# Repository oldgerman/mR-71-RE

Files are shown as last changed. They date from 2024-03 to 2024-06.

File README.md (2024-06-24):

## mR-71-RE

mR-71-RE 是基于 [Andrey_B](https://www.radiokot.ru/forum/memberlist.php?mode=viewprofile&u=21307) 的作品 [交流欧姆表 mR-71](https://radiokot.ru/artfiles/6673/) 修改的

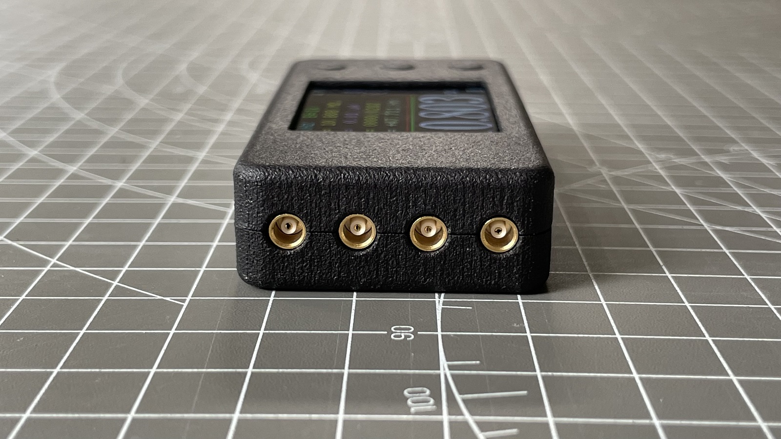
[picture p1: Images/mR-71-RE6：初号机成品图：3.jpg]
|  |
| ------------------------------------------ |

## 关于

mR-71 重制版的制造文件（mR-71 Remastered version manufacturing files）

你第一次接触到本套文件可能是压缩包，制造文件的版本可能滞后于仓库，制作前请访问[仓库地址](https://github.com/oldgerman/mR-71-RE)检查更新

The first time you come into contact with this set of files, it may be a compressed package, and the content may lag behind the warehouse. Please visit the [github](https://github.com/oldgerman/mR-71-RE) to check for updates before making

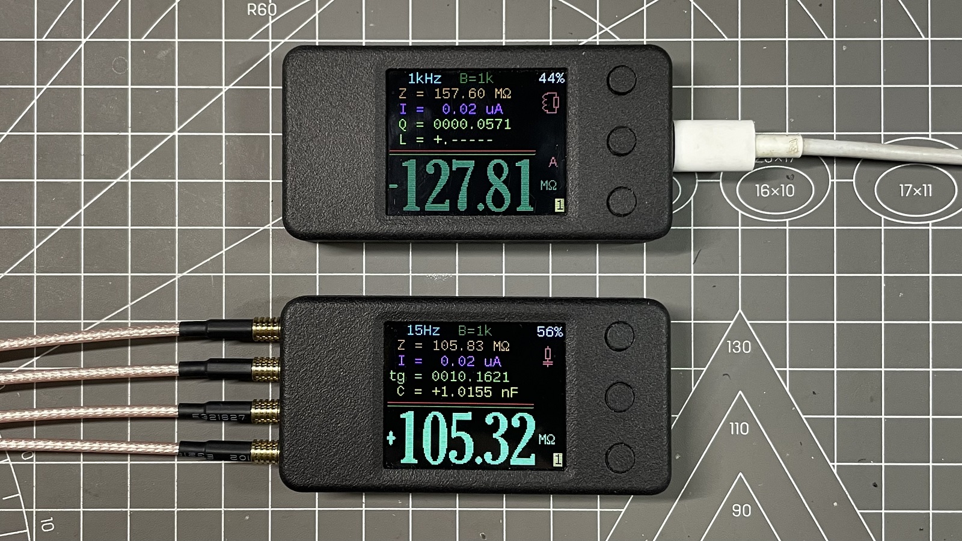
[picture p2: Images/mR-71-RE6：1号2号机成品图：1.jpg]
mR-71-RE6：1号2号机成品图：2
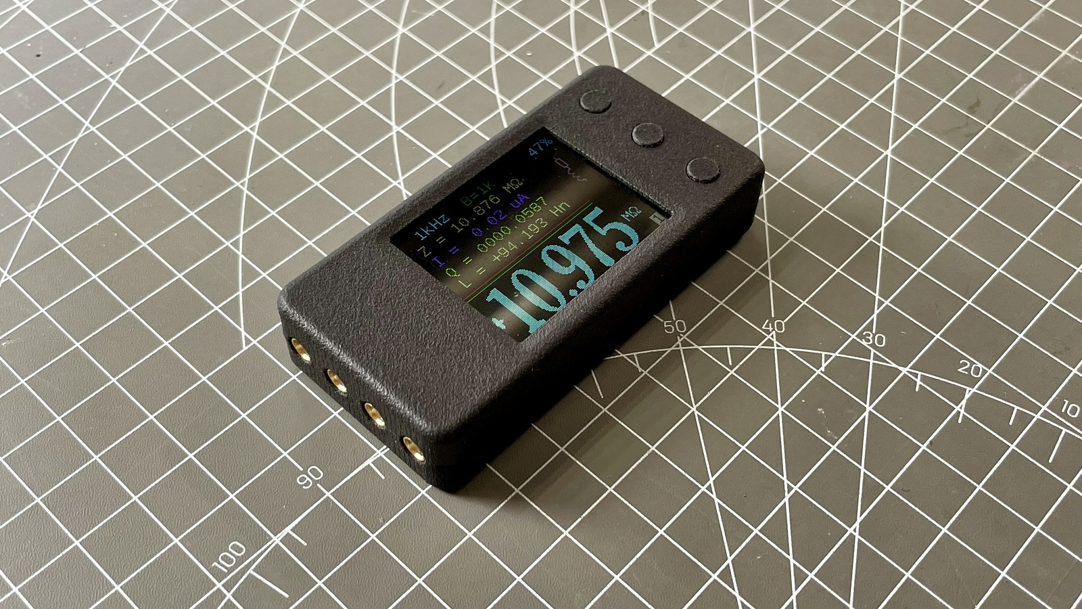
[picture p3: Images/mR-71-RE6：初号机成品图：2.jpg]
|  |  |
| --- | --- |
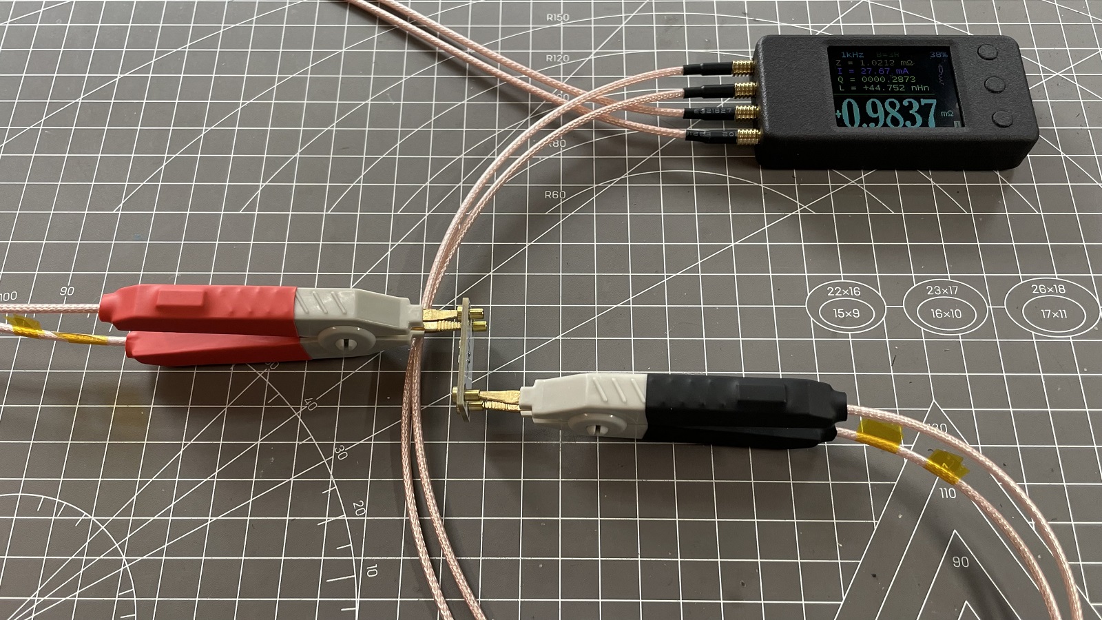
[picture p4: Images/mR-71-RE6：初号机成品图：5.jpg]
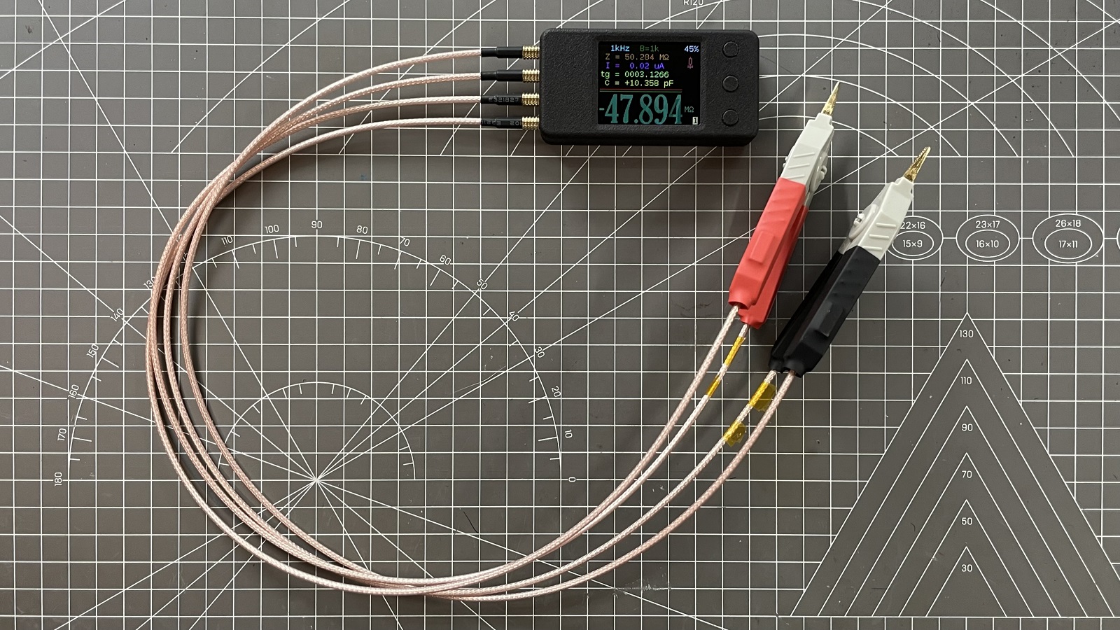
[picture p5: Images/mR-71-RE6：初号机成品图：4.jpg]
|  |  |

### 路径下各个文件夹的说明

```c
├─AD_Projects                     // # PCB的源文件
│  └─MR-71_RE0                    // # 原版mR-71重绘工程
├─BOM                             // # PCB的物料清单
├─Gerber                          // # 打板文件
│  ├─Kelvin_Clip_RG316_To_PCB     // ## 【2层，板厚1.6mm】RG316转接板
│  ├─Kelvin_RES                   // ## 【2层，板厚1.6mm】开尔文焊盘电阻测试板
│  ├─mR-71-RE                     // ## 【4层，板厚1.0mm】主板PCB打样文件
│  └─mR-71_RE_Stencil             // ## 主板开钢网的文件
├─Hex                             // # 固件: 反汇编修改v0.2固件，以适配IPS屏幕
├─Images                          // # 图片
├─Schematic                       // # 原理图
├─SMT                             // # SMT文件
└─STL                             // # 3D打印模型
    ├─link_parts                  // ## 连接模型
    └─single_parts                // ## 单个模型
```

### 快速下载某个文件

如果你想单独下载某个文件，可以顺着文件路径一路点击到对应的文件，点击下载raw文件：

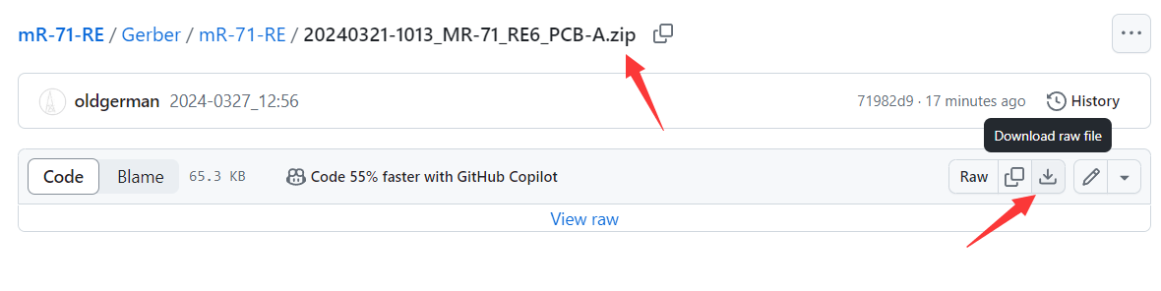
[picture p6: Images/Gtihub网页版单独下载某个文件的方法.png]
Gtihub网页版单独下载某个文件的方法


### 注意事项

- 主板 PCB 打板厚度是 1mm，否则外壳会装配不好
- PCB、原理图、钢网、外壳文件后续可能会改动，以最新的日期时间为准！

### 了解更多

- [mR-71-RE组装指南](https://oldgerman.github.io/1d2ecca7/)（网页版，可以使用浏览器翻译），本仓库根目录有 PDF 版
- [mR-71-RE校准测试](https://oldgerman.github.io/b8304ba5/)（网页版，可以使用浏览器翻译），本仓库根目录有 PDF 版

### 更新日志

| 日期 | 概述 | 制造文件变动 | 备注 |
| --- | --- | --- | --- |
| 2024-0319 | 首次发布 | 主机 PCB 版本：v1.0 | 组装教程、3D 打印外壳也都上传了 |
| 2024-0321 | 更新主机 PCB 版本、钢网、原理图 | 主机PCB版本：v1.1 | 还添加了小于 20% 沉金面积版本，后缀 Gold |
| 2024-0325 | 更新成品图 | 无 | 无 |
| 2024-0327 | 添加 mR-71-RE 上板和下板单独的 Gerber 文件 | 无 | 详见 [Gerber文件说明：mR-71-RE](https://github.com/oldgerman/mR-71-RE/blob/master/Gerber/mR-71-RE/README.md) |
| 2024-0408 | 添加 组装指南 和 校准测试 网页版文章的 PDF 版 | 原理图、BOM、ibom | 网页版文章的 PDF 版在仓库根目录下 |
| 2024-0416 | 添加 Kelvin_RES 焊盘 2512 和 1206 单独的 Gerber 文件 | 无 | 详见 [Gerber文件说明：Kelvin_RES](https://github.com/oldgerman/mR-71-RE/blob/master/Gerber/Kelvin_RES/README.md) |
| 2024-0418 | 修正 BOM 表 R31 R32 封装，从 0402 改为 0603 | 原理图、BOM | 物料种类未变 |
| 2024-0420 | 修正 BOM 表 C22 厂家型号为 CL05B103KB5NNNC | BOM | 物料种类变化 |
| 2024-0430 | 重命名交互式 BOM 文件 20240408_MR-71_RE6_BOM.html 为 20240420_MR-71_RE6_BOM.html | ibom | 仅重命名，防止不必要的误解（以为 BOM 更新了但 ibom 还是旧版本对不上号） |
| 2024-0511 | 添加 mR-71-RE 的 SMT 坐标文件 | 坐标文件 | 不同 PCB 需使用对应的坐标文件，在 [SMT](https://github.com/oldgerman/mR-71-RE/blob/master/SMT) 文件夹 |
| 2024-0512 | 添加 AD 重绘的原版 mR-71 工程 | 无 | 详见 [源文件说明：mR-71-RE0](https://github.com/oldgerman/mR-71-RE/blob/master/AD_Projects/MR-71_RE0/README.md) |
| 2024-0624 | 添加 Kelvin_RES 焊盘 2512 和 1206 单元的 Gerber 文件 | 无 | 详见 [Gerber文件说明：Kelvin_RES](https://github.com/oldgerman/mR-71-RE/blob/master/Gerber/Kelvin_RES/README.md) |

## 致谢

- 感谢 [mR-71](https://radiokot.ru/artfiles/6673/) 原作者 [Andrey_B](https://www.radiokot.ru/forum/memberlist.php?mode=viewprofile&u=21307)
- 感谢一同玩 mR-71 的老友们
- 感谢 JLC 和 JP 的板子

## 许可协议

[CC BY-NC-SA 4.0 DEED | 署名-非商业性使用-相同方式共享 4.0 国际](https://creativecommons.org/licenses/by-nc-sa/4.0/deed.zh-hans)



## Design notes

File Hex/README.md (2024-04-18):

## hex文件说明

### 20240418_mR-71_v0.2_FW_std_ida_func(ips_ok+sub_8003e90_to_foo2).hex

BUG修复：

- hex文件最后缺少回车换行，某些下载器会无法正常加载，已添加，感谢 硬汉哥 [指出BUG](https://www.armbbs.cn/forum.php?mod=redirect&goto=findpost&ptid=123517&pid=304299&fromuid=47676)

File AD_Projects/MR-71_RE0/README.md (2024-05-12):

## 源文件说明：mR-71-RE0

原版 mR-71 的 PCB 和 SCH 作者 Andery_B 使用 Sprint-Layout 绘制，没有分享源文件，因此使用其他主流 EDA 演绎非常不方便

此文件夹下是我用 Altium 23.3.1 重绘的 原版 mR-71 工程，原理图遵循原版的风格，PCB按照原版的走线方式布通，但线宽过孔按键开孔等未优化，**仅供参考，不保证做出来可以正常工作**，如果你想设计 原版 mR-71 的衍生版本，不如从这套源文件开始

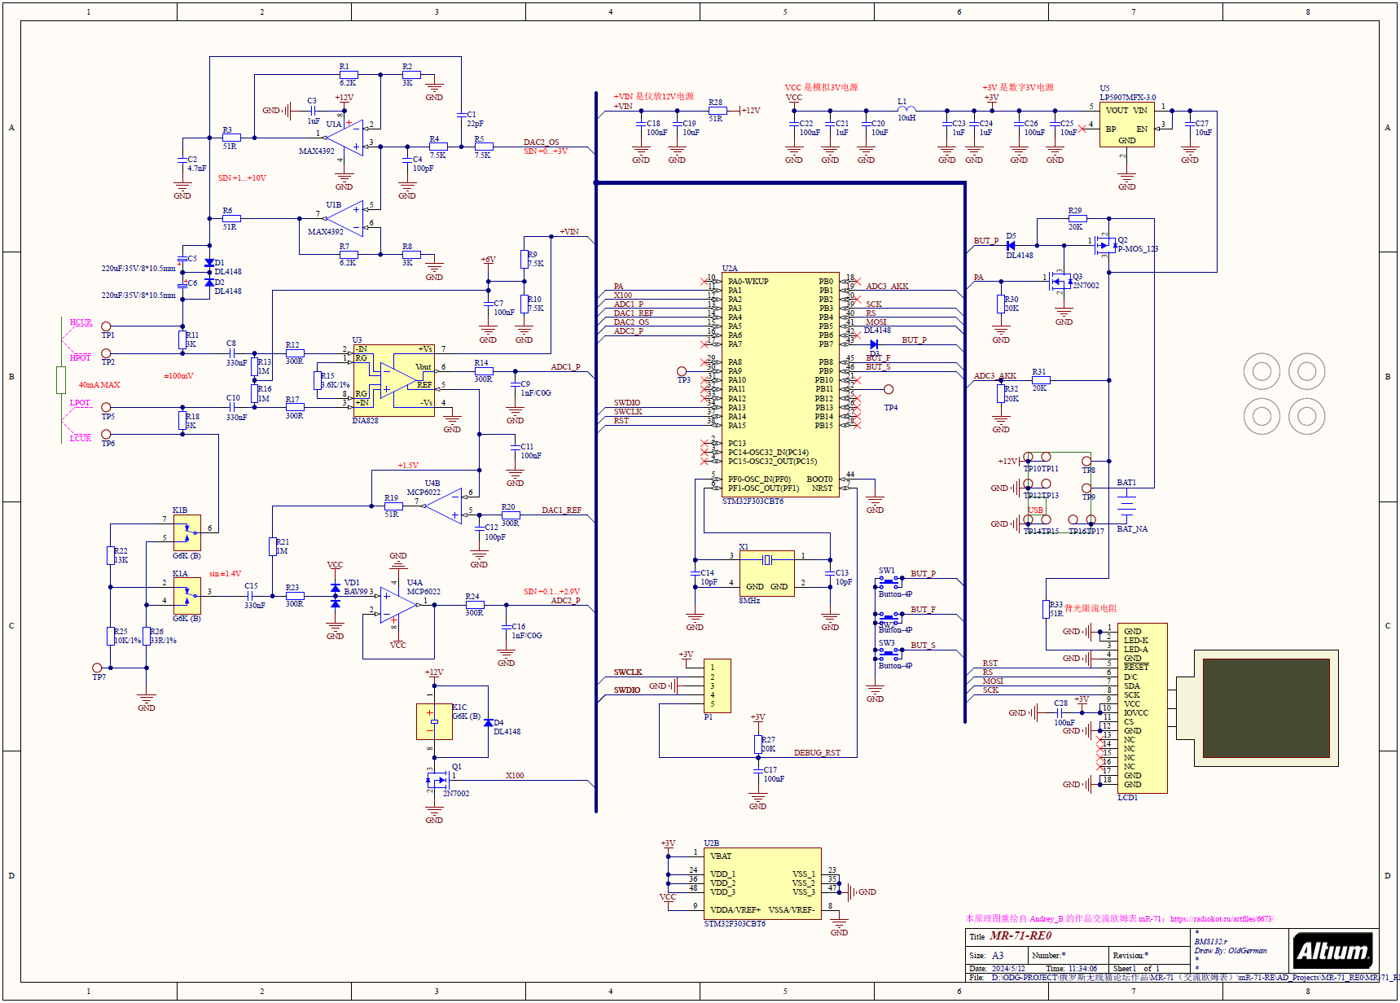
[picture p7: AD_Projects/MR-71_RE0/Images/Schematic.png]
SCH


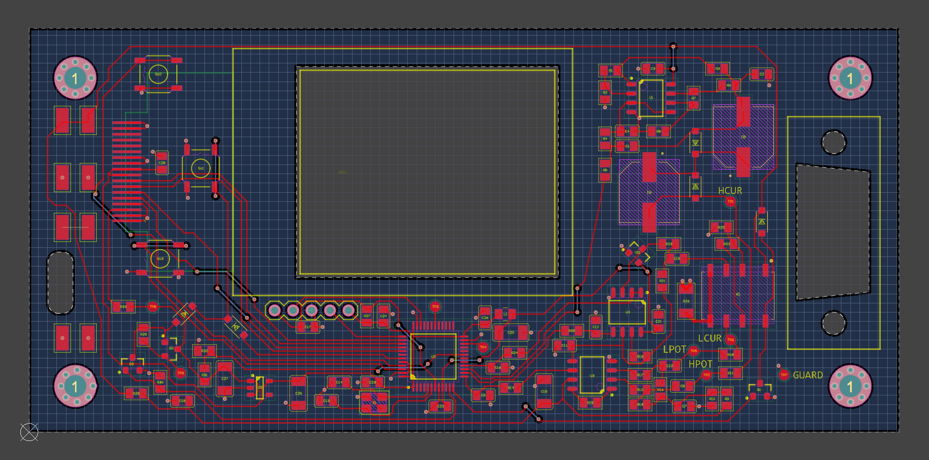
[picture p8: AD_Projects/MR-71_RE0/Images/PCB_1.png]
PCB_1


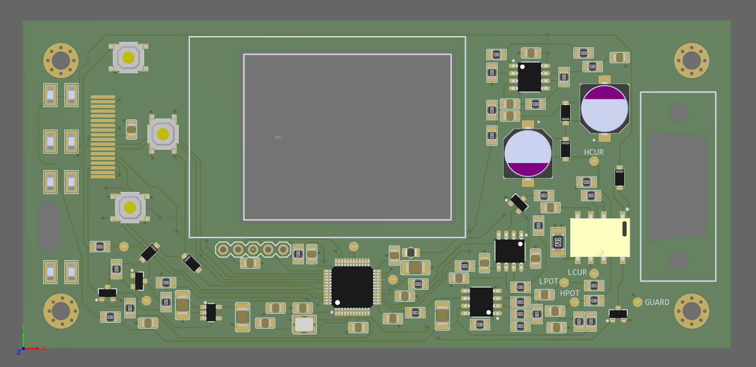
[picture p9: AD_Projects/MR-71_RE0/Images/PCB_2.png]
PCB_2


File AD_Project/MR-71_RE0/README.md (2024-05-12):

## 源文件说明：mR-71-RE0

原版 mR-71 的 PCB 和 SCH 作者 Andery_B 使用 Sprint-Layout 绘制，没有分享源文件，因此使用其他主流 EDA 演绎非常不方便

此文件夹下是我用 Altium 23.3.1 重绘的 原版 mR-71 工程，原理图遵循原版的风格，PCB按照原版的走线方式布通，但线宽过孔等未优化，**仅供参考，不保证做出来可以正常工作**，如果你想设计 原版 mR-71 的衍生版本，不如从这套源文件开始

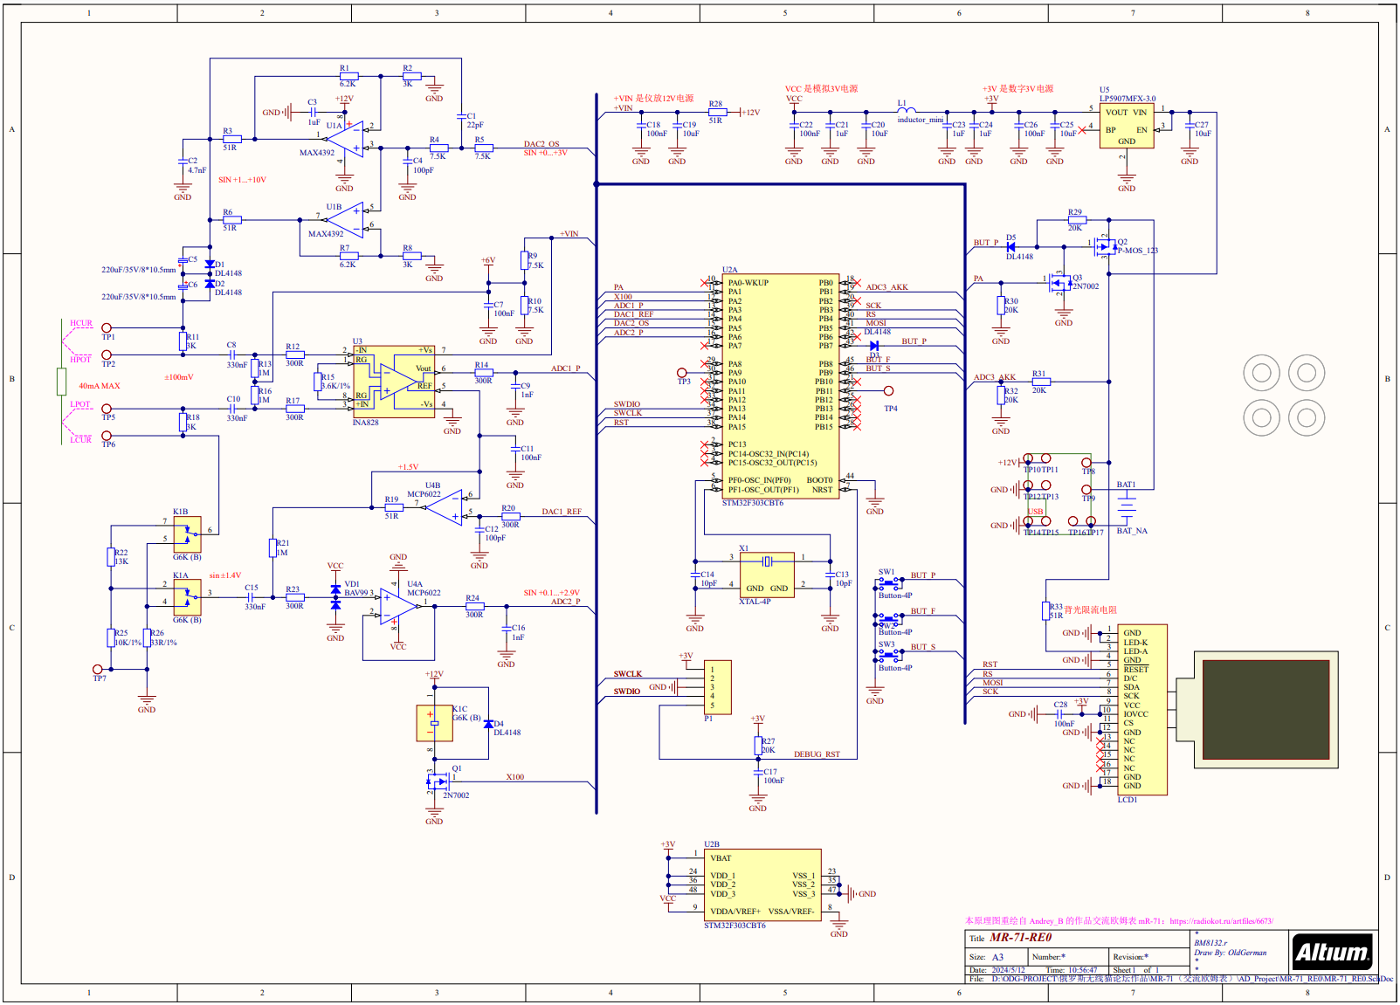
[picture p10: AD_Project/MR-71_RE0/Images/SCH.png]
SCH


PCB_1

PCB_2

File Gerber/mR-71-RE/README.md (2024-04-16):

## Gerber文件说明：mR-71-RE

### 文件名：组成

```c
AAAABBCC-DDEE_MR-71_RE6_####.zip
^~~~^~^~ ^~^~ ^~~~~~~~^ ^~~~ ^~~
年  月 日 时 分 名称  版本 后缀  格式
^~~~~~~~~~~~~
前缀
```

例如：20240321-1013_MR-71_RE6_Gold.zip 文件名的意思是：2024年3月31日MR-71-RE第6版沉金

### 文件名：前缀：日期

优先使用最新日期的文件，同一天日期后的小时分钟不分先后

### 文件名：后缀

- 无：上板和下板拼成一个板的文件，得看审核运气，若被当作拼版，就单独打后缀为 PCB-A 和 PCB-B 的文件
- Gold：小于20%沉金面积的，可用JLC沉金通用券，但得看审核运气，可能被当作拼版，不能用券
- PCB-A：上板（有显示屏、按钮的板子）
- PCB-B：下板（有主控、电源、运放的板子）

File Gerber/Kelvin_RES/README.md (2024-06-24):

## Gerber文件说明：Kelvin_RES

### 文件名：组成

```c
AAAABBCC-DDEE_Kelvin_RES_v1.0.zip
^~~~^~^~ ^~^~ ^~~~~~~~~~ ^~~~ ^~~
年  月 日 时 分 名称        版本 格式
^~~~~~~~~~~~~
前缀
```

例如：20240314-1629_Kelvin_RES_v1.0 文件名的意思是：2024年3月14日Kelvin_RES第1.0版

### 文件名：前缀：日期

优先使用最新日期的文件，同一天日期后的小时分钟不分先后

### PCB预览

#### Kelvin_RES_v1.0

同时有2512和1206焊盘

| 正面 | 反面 |
| --- | --- |
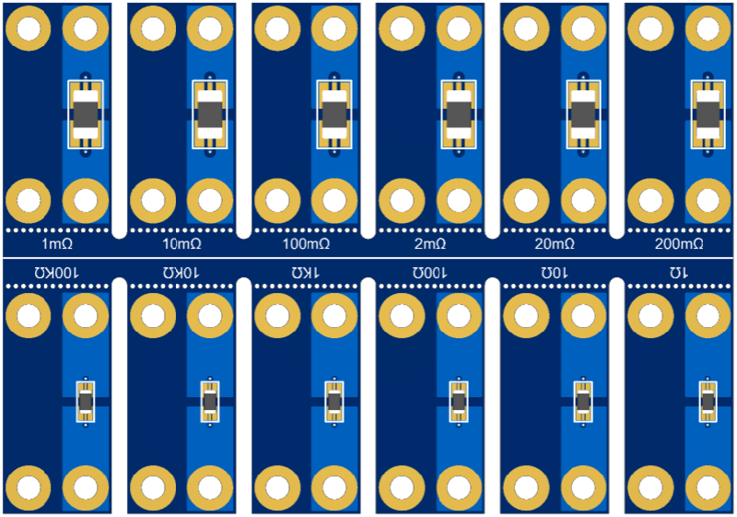
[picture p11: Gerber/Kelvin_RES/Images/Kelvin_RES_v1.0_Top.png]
Kelvin_RES_v1.0_Top
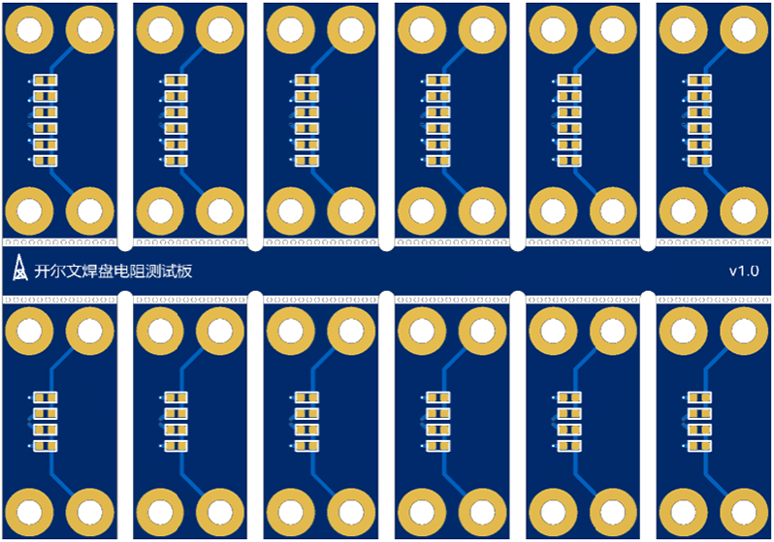
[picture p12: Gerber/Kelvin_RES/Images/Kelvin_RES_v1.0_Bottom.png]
Kelvin_RES_v1.0_Bottom
|  |  |

#### Kelvin_RES_1206_v1.0

只有1206焊盘

| 正面 | 反面 |
| --- | --- |
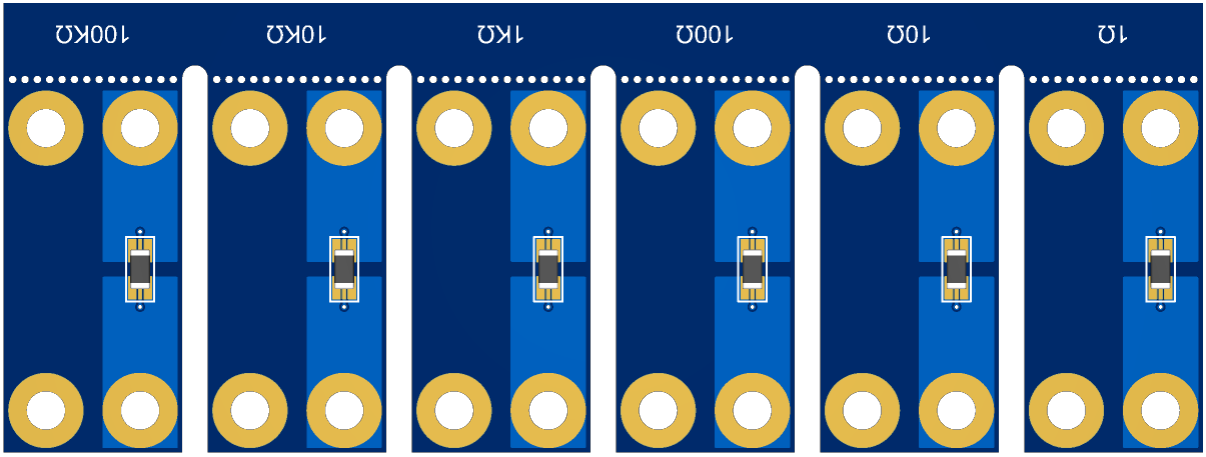
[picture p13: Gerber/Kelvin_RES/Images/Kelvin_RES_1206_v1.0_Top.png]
Kelvin_RES_1206_v1.0_Top
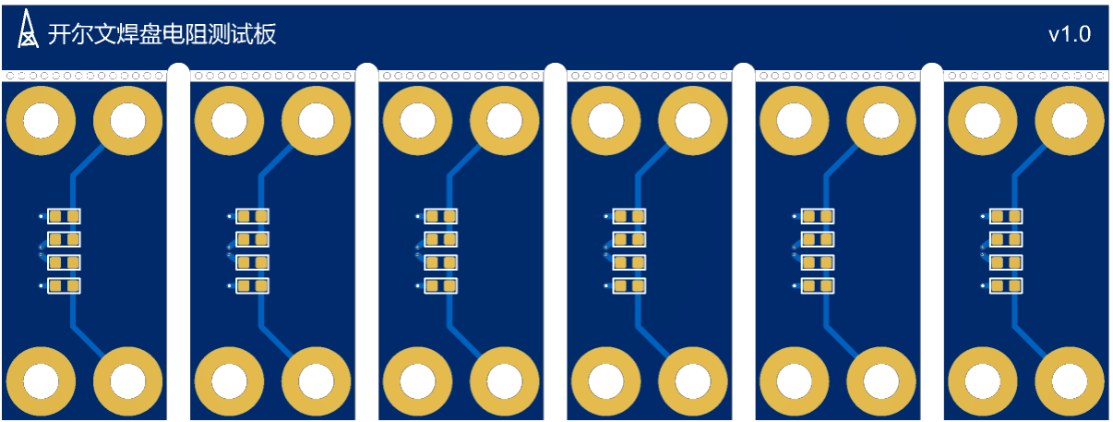
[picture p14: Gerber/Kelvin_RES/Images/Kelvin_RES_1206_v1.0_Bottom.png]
Kelvin_RES_1206_v1.0_Bottom
|  |  |

#### Kelvin_RES_2512_v1.0

只有2512焊盘

| 正面 | 反面 |
| --- | --- |
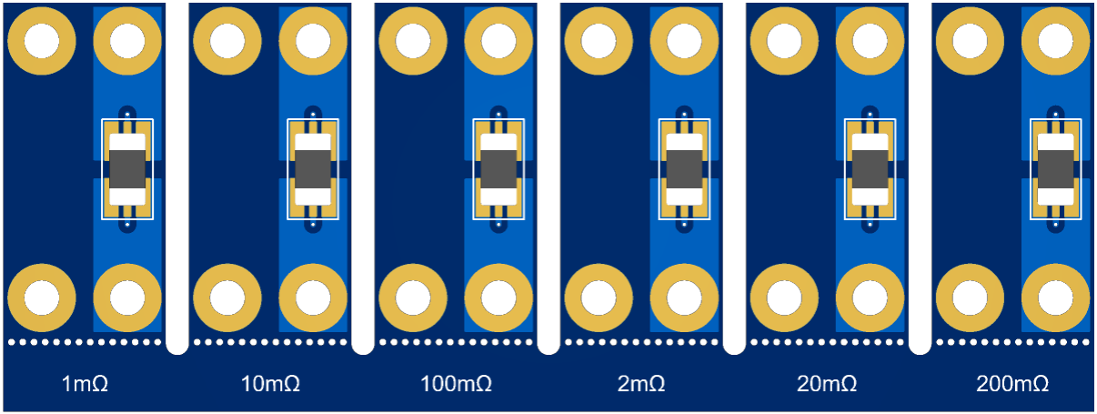
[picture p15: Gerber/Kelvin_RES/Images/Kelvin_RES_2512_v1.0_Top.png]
Kelvin_RES_2512_v1.0_Top
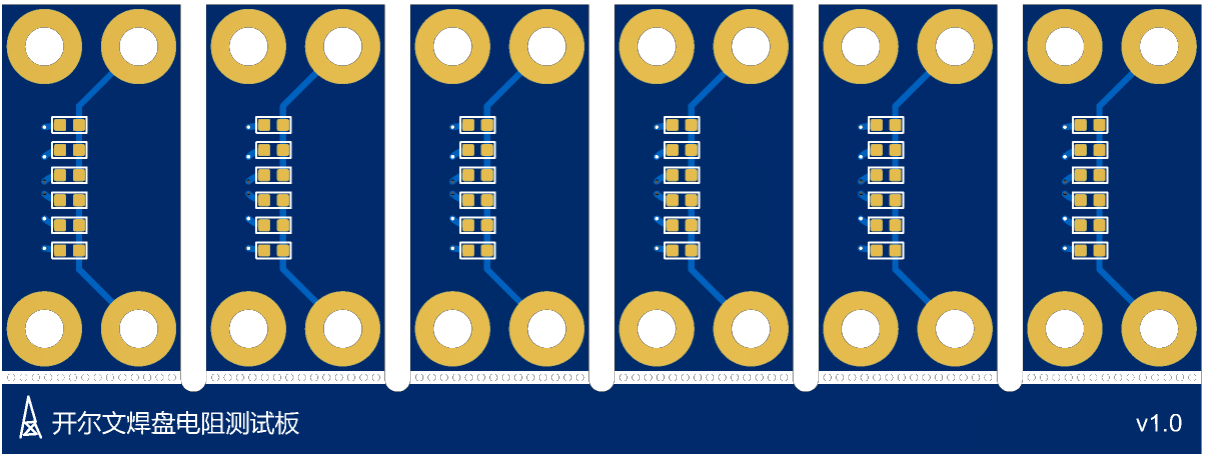
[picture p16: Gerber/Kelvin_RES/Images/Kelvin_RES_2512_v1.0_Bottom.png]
Kelvin_RES_2512_v1.0_Bottom
|  |  |

#### Kelvin_RES_Unit_1206_v1.0

| 正面 | 反面 |
| --- | --- |
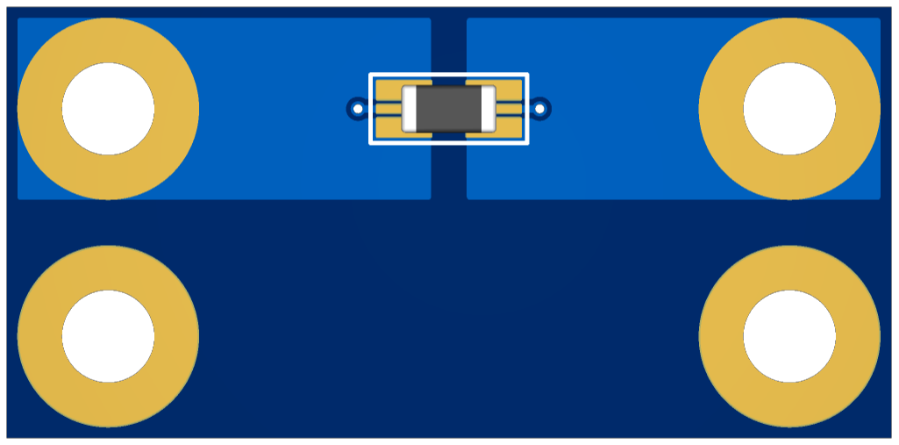
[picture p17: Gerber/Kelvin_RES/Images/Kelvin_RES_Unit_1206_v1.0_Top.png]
Kelvin_RES_Unit_1206_v1.0_Top
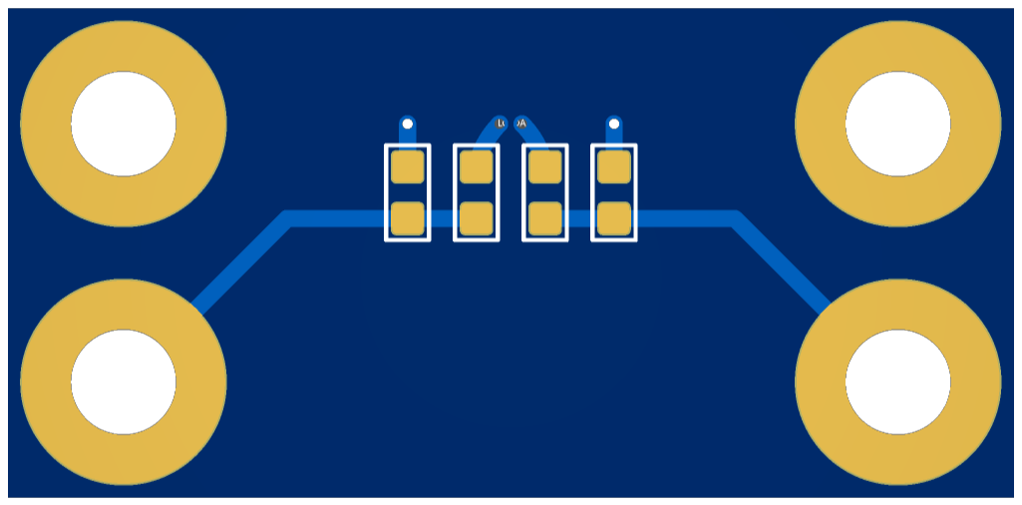
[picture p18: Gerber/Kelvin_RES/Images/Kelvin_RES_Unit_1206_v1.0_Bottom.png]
Kelvin_RES_Unit_1206_v1.0_Bottom
|  |  |

#### Kelvin_RES_Unit_2512_v1.0

| 正面 | 反面 |
| --- | --- |
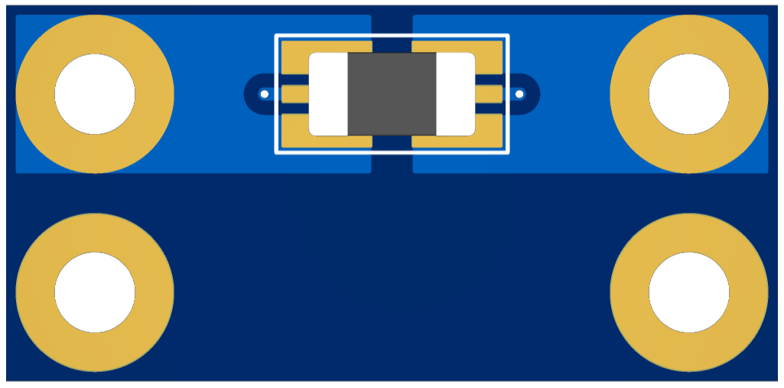
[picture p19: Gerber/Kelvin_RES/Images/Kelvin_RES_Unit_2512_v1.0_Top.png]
Kelvin_RES_Unit_2512_v1.0_Top
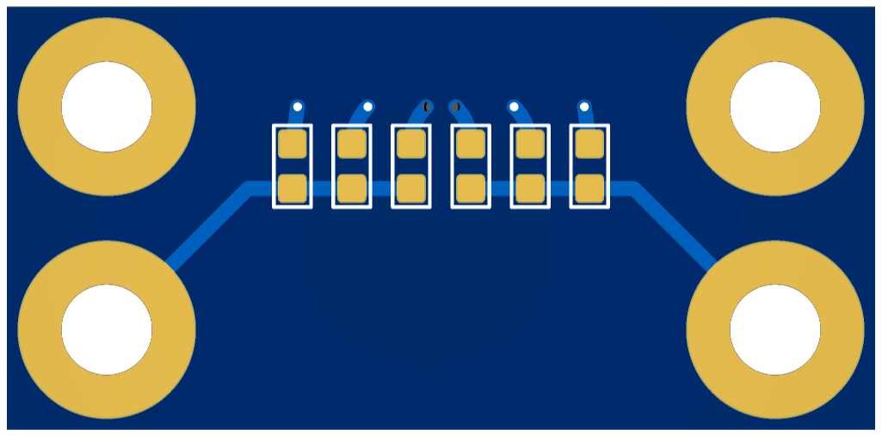
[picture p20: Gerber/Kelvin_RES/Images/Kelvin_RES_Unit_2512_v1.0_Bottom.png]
Kelvin_RES_Unit_2512_v1.0_Bottom
|  |  |

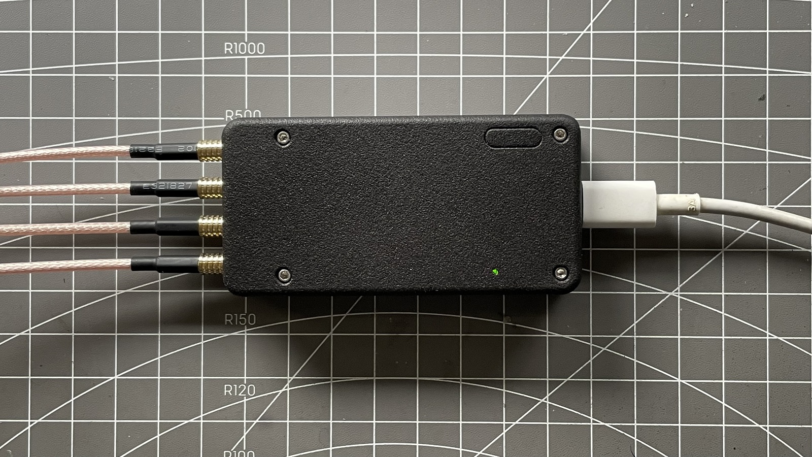
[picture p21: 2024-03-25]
Images/mR-71-RE_T：充电指示灯：充电完成：绿色.JPG

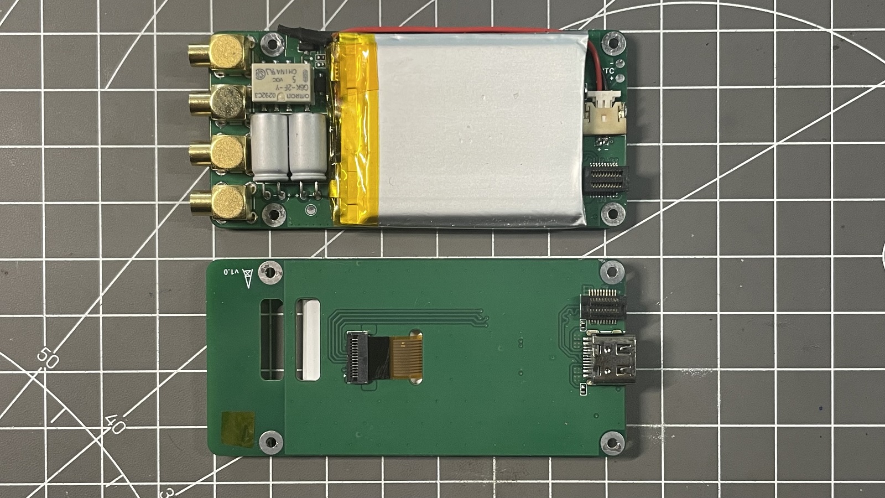
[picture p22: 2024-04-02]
Images/mR-71-RE：v1.0_PCB：2.JPG

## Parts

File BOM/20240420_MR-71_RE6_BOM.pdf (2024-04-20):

参数 | 描述 | 位号 | 封装 | 数量 | 每个价格 总价格 | | 报价参考 | 品牌 | 厂家型号 | 备注
CONN_X4 | | P1 | 2.54mm_Male_x4 180H NO SLIKSCREEN 1 | | 0 | 0
AD8066 | Amplifier | U1 | ANALOG DEV SOIC-8 R8 | 1 | 10.8 | 10.8 | 优信电子 | ADI
AD8606 | Amplifier | U3 | ANALOG DEV SOIC-8 R8 | 1 | 7.8 | 7.8 | 优信电子 | ADI
AD8221ARMZ | Precision Instrumentation Amplifier | U2 | ANALOG MSOP-8 RM-8 | 1 | 11.8 | 11.8 | 优信电子 | ADI
LP5907MFX-3.0 | 超低噪声线性稳压芯片 | U4, U6 | ANALOG TSOT-23-5 UJ-5 | 2 | 1.4 | 2.8 | 优信电子 | Ti
CONN_B2B_2X10 | | J5 | B2B-0.5mm-20P-F_MEDIUM | 1 | 1 | 1 | 山谷道 | 山谷道板对板连接器 | 高精密镀金0.5MM间距双槽板对板BTB连接器2*10Pin母座，合高6mm
CONN_B2B_2X10 | | J6 | B2B-0.5mm-20P-M_MEDIUM | 1 | 1 | 1 | 山谷道 | 山谷道板对板连接器 | 高精密镀金0.5MM间距双槽板对板BTB连接器2*10Pin公座，合高6mm
1nF/C0G | Capacitor | C20, C67 | C0402 | 2 | 0.014 | 0.028 | LCSC | 风华 | 0402CG102J500NT
1uF | Capacitor | C9, C10, C17, C18, C24, C26, C47, C57, C64 | C0402 | 9 | 0.024 | 0.216 | LCSC | 三星 | CL05A105KA5NQNC
10nF/DNP | Capacitor | C22 | C0402 | 1 | 0.007 | 0.007 | LCSC | 三星 | CL05B103KB5NNNC
12pF | Capacitor | C55, C56 | C0402 | 2 | 0.006 | 0.012 | | 国巨 | CC0402JRNPO9BN120
22pF/C0G | Capacitor | C2 | C0402 | 1 | 0.006 | 0.006 | | 国巨 | CC0402JRNPO9BN220
100nF | Capacitor | C12, C35, C36, C48, C52, C53, | C0402 | 12 | 0.035 | 0.42 | LCSC | 三星 | CL05B104KB54PNC
100pF/C0G | Capacitor | C4 | C0402 | 1 | 0.006 | 0.006 | LCSC | 国巨 | CC0402JRNPO9BN101
DNP | Capacitor | C1, C6, C11, C29 | C0402 | 4 | 0 | 0
DNP/47nF | Capacitor | C68 | C0402 | 1 | 0 | 0
1uF/X7R | Capacitor | C49 | C0603 | 1 | 0.018 | 0.018 | LCSC | 国巨 | CC0603KRX7R9BB105
2.2uF/DNP | Capacitor | C27 | C0603 | 1 | 0.04 | 0.04 | LCSC | 三星 | CL10A225KO8NNNC
4.7nF/C0G | Capacitor | C3, C70 | C0603 | 2 | 0.084 | 0.168 | LCSC | 村田 | GRM1885C1H472JA01D
4.7uF | Capacitor | C59 | C0603 | 1 | 0.1 | 0.1 | LCSC | 三星 | CL10A475KA8NQNC
10uF | Capacitor | C32, C33, C34, C37, C38, C63 | C0603 | 6 | 0.11 | 0.66 | LCSC | 三星 | CL10A106MA8NRNC
100nF | Capacitor | C31, C66 | C0603 | 2 | 0.016 | 0.032 | LCSC | 三星 | CL10B104KB8NNNC
10uF | Capacitor | C41, C42, C43, C44, C45, C46, C50, C51, C65 | C0805 | 9 | 0.169 | 1.521 | LCSC | 三星 | CL21B106KOQNNNE
DNP/1uF | Capacitor | C25 | C0805 | 1 | 0 | 0
10uF | Capacitor | C30, C39, C40 | C1206 | 3 | 0.34 | 1.02 | LCSC | 三星 | CL31B106KBHNNNE
220nF/50V/C0G | Capacitor | C5, C19, C21, C28 | C1206 | 4 | 1.4 | 5.6 | auwah旗舰店 | 村田 | GRM31C5C1H224JE02L
220uF/35V | Capacitor | C14 | CAP AL DIP -90 D=6.3 L=12.1 | 1 | 2 | 2 | LCSC | 永铭 | NPXC1101V221MJTM
220uF/35V | Capacitor | C13 | CAP AL DIP +90 D=6.3 L=12.1 | 1 | 2 | 2 | LCSC | 永铭 | NPXC1101V221MJTM
22uF/10V | Capacitor | C7, C8, C15, C16 | CAP_POL_3216 | 4 | 0.51 | 2.04 | 优信电子 | AVX | TAJA226K010RNJ
22uF/10V, 47uF/6.3V | Capacitor | C23 | CAP_POL_3216 | 1 | 0.33 | 0.33 | 优信电子 | AVX | TAJA476K006RNJ
BAV199W | Dual Series Switching Diodes | VD1, VD2, VD3 | DIODES SOT-323-3 | 3 | 0.26 | 0.78 | LCSC | DIODES(美台) | BAV199W-7
8MHz | 4脚无源石英晶振 | X1 | EPSON TSX-3225 | 1 | 0.9 | 0.9 | LCSC | YXC | X32258MOB4SI
1K@100MHz | 贴片磁珠 | L1, L2, L3, L4, L5, L6, L7, L12 | FER0603 | 8 | 0.047 | 0.376 | LCSC | 村田 | BLM18AG102SN1D
1K@100MHz | 贴片磁珠 | L8, L11, L13 | FER0805 | 3 | 0.21 | 0.63 | LCSC | 村田 | BLM21AG102SN1D
TP5000 | 2A开关型4.2V锂电池/3.6V铁锂电池充电器 | U5 | HVQFN-16 4X4MM 0.65 | 1 | 1.4 | 1.4 | 优信电子 | TOPPOWER
2.2uH | 功率电感 | L10 | INDUCTOR 0420 4.6X4.1X2MM | 1 | 0.28 | 0.28 | 优信电子 | | 0420一体成型电感
4.7uH | 功率电感 | L9 | INDUCTOR 0420 4.6X4.1X2MM | 1 | 0.28 | 0.28 | 优信电子 | | 0420一体成型电感
2N7002K | N-MOS | Q1, Q3 | INFINEON SOT-23-3 | 2 | 0.19 | 0.38 | 优信电子 | 威世 | 2N7002K-T1-GE3
BAT54C | 贴片肖特基二极管 | D5 | INFINEON SOT-23-3 | 1 | 0.08 | 0.08 | 优信电子 | 安世 | BAT54C，215
SI2301 | P-MOS | Q2 | INFINEON SOT-23-3 | 1 | 0.21 | 0.21 | 优信电子 | 威世 | SI2301CDS
LCD_Universal_128x160_14pin+CONN | | LCD2 | LCD-128X160-1.77INCH_IPS_PlUG_FLIP_BACK_FH34SRJ-14S-0.5SH(50) 1 | | 0.885 | 0.885 | LCSC | JS(钜硕电子) | AFC42-S14FMA-1H | 立创有这个品牌的16-15券
LCD_Universal_128x160_14pin+SOLDER | | LCD1 | LCD-128X160-1.77INCH_IPS_SOLDER_FLIP_TOP 1 | | 8.5 | 8.5 | 耀元鸿科技 | | 1.8寸IPS全视角插接款，找客服改价要IPS，没上架IPS的型号 | 焊接款也可以，省插接的屏幕座子，看个人
黄绿色 | LED | LED2 | LED0603_GREEN | 1 | 0.068 | 0.068 | LCSC | 国星光电 | NCD0603C1
红色 | LED | LED1 | LED0603_RED | 1 | 0.059 | 0.059 | LCSC | 国星光电 | NCD0603R1
3.7V/503443/850mA | 锂电池 | BAT1 | Lipo_NONE | 1 | 5.5 | 5.5 | 林琳电子 | | 503443电池 3.7V 850mA 带保护板
CONN_MCX | MCX Connector Jack | J1, J2, J3, J4 | MCX_WE_60611002111502 | 4 | 3.61 | 14.44 | LCSC | 蝙蝠无线 | BWMCX-KWE | 立创有这个品牌的16-15券
USBLC6-2 | Very low capacitance ESD protection | U10 | MICROCHIP SOT-23-6 M6 | 1 | 0.38 | 0.38 | 优信电子 | ST | USBLC6-2SC6
CONN_X2 MOLEX 53780-0270 / 51146-0200 | | P2 | MOLEX_53780-0270+MOLEX_51146-0200 MINI 1 | | 0.45 | 0.45 | LCSC | Megastar(兆星) | ZX-MX1.25-2PCB | 立创有这个品牌的16-15券，另需在淘宝买1.25mm超薄2P端子线
UMH3N | NPN型带阻双三极管 | Q4 | ON SEMI SOT-363 | 1 | 0.33 | 0.33 | LCSC | CJ
0R | IEC Standard | R6, R33, R41 | R0402 | 3 | 0.003 | 0.009
0R/51R | IEC Standard | R27 | R0402 | 1 | 0.003 | 0.003
1K | IEC Standard, Resistor | R36, R38, R56 | R0402 | 3 | 0.003 | 0.009
1M | IEC Standard | R7 | R0402 | 2 | 0.003 | 0.006
1.5K | IEC Standard | R66 | R0402 | 1 | 0.003 | 0.003
3K | IEC Standard | R2, R13 | R0402 | 2 | 0.003 | 0.006
5.1K | IEC Standard | R14, R64, R65 | R0402 | 3 | 0.003 | 0.009
6.2K | IEC Standard | R1, R12, R43 | R0402 | 3 | 0.003 | 0.009
6.98K | IEC Standard | R15 | R0402 | 1 | 0.003 | 0.003
7.5K | IEC Standard | R4, R5 | R0402 | 2 | 0.003 | 0.006
10K | IEC Standard, Resistor | R10, R40, R53, R55, R61 | R0402 | 5 | 0.003 | 0.015
20K | IEC Standard | R39, R42, R44, R45, R58 | R0402 | 5 | 0.003 | 0.015
33R | IEC Standard | R21, R57, R59, R60, R68 | R0402 | 5 | 0.003 | 0.015
48.7K | IEC Standard | R51 | R0402 | 1 | 0.003 | 0.003
51R | IEC Standard | R3, R9 | R0402 | 2 | 0.003 | 0.006
100K | IEC Standard | R11, R28, R29 | R0402 | 3 | 0.003 | 0.009
130K | IEC Standard | R54 | R0402 | 1 | 0.003 | 0.003
200K/2K | IEC Standard | R26 | R0402 | 1 | 0.003 | 0.003
205K | IEC Standard | R48 | R0402 | 1 | 0.003 | 0.003
300R | IEC Standard | R19, R49, R69 | R0402 | 4 | 0.003 | 0.012
402K | IEC Standard | R52 | R0402 | 1 | 0.003 | 0.003
470K | IEC Standard | R50 | R0402 | 1 | 0.003 | 0.003
649K | IEC Standard | R47 | R0402 | 1 | 0.003 | 0.003
DNP | IEC Standard | R8 | R0402 | 1 | 0.003 | 0.003
0R/DNP | IEC Standard | R37 | R0603 | 1 | 0.006 | 0.006
0R/NTC-10K | IEC Standard | R67 | R0603 | 1 | 0.006 | 0.006
1M | IEC Standard | R18, R23, R31, R62 | R0603 | 3 | 0.006 | 0.018
3K | IEC Standard | R16, R25 | R0603 | 2 | 0.006 | 0.012
3.57K/0.1%, 3.6K/0.1%||300K/0.1% | IEC Standard | R22 | R0603 | 1 | 0.14 | 0.14 | LCSC | 光颉
10K/1%/0.1% | IEC Standard | R34 | R0603 | 1 | 0.14 | 0.14 | LCSC | 光颉
10R | IEC Standard | R63 | R0603 | 1 | 0.006 | 0.006
13K | IEC Standard | R30 | R0603 | 1 | 0.14 | 0.14 | LCSC | 光颉
300R | IEC Standard | R17, R24, R32 | R0603 | 2 | 0.006 | 0.012
DNP/1M | IEC Standard | R20 | R0603 | 1 | 0 | 0
0.25R | IEC Standard | R46 | R1206 | 1 | 0.035 | 0.035 | LCSC | EVER OHMS | CR1206FR250P05R
33R/1%/0.1% | IEC Standard | R35 | R1206 | 1 | 0.28 | 0.28 | LCSC | 国巨 | RT1206BRD0733RL
G6K (B) | Telecom Relay DPDT (2 Form C) Surface MountK1 | | RELAY_G6K-2F-Y | 1 | 5.95 | 5.95 | LCSC | 欧姆龙 | G6K-2F-Y-TR DC5
DNP/SMAFJ26CA | 极性：Bidirectional | D4, D14, D15 | SMAF - BI | 3 | 0 | 0
1N4148W | 二极管 | D1, D2, D3, D7 | SOD123F | 4 | 0.064 | 0.256 | LCSC | CJ
DSK24/40V/2A | 二极管 | D6, D12, D13, D16 | SOD123F | 4 | 0.2 | 0.8 | 优信电子 | MDD
BZX384-B3V3 | 二极管 | D8, D9 | SOD-323 | 2 | 0.33 | 0.66 | 优信电子 | 安世
BZX384-B5V6 | 二极管 | D10, D11 | SOD-323 | 2 | 0.16 | 0.32 | 优信电子 | 安世
STM32F303CBT6 | 带DSP和FPU的主流混合信号ARM Cortex-M4 MCU U9 | | ST LQFP-48 7x7MM | 1 | 8.5 | 8.5 | 优信电子 | ST
Button-4P | Button | SW1, SW2, SW3, SW4, SW5 | TACTILE_SWITCH_SMD_4X4MM_NO_CASE5 | | 0.05 | 0.25 | 优信电子 | | 薄膜按键开关 4*4*0.8
TPS63000 | Buck-Boost Converter | U7 | TI PVSON-10 3x3MM DRC | 1 | 2.6 | 2.6 | 优信电子 | Ti | TPS63000DRCR
Type-C | | USB1 | Type-C-TOP | 1 | 0.23 | 0.23 | 优信电子 | | Type-C 16p
LM27762 (B) | Charge Pump Switching Regulator Adjustable -5V or +5V Dual Output 250mA U8 | | WSON-12-2X3MM VIA | 1 | 3.2 | 3.2 | 优信电子 | Ti | LM27762DSSR
合计 | 111.072

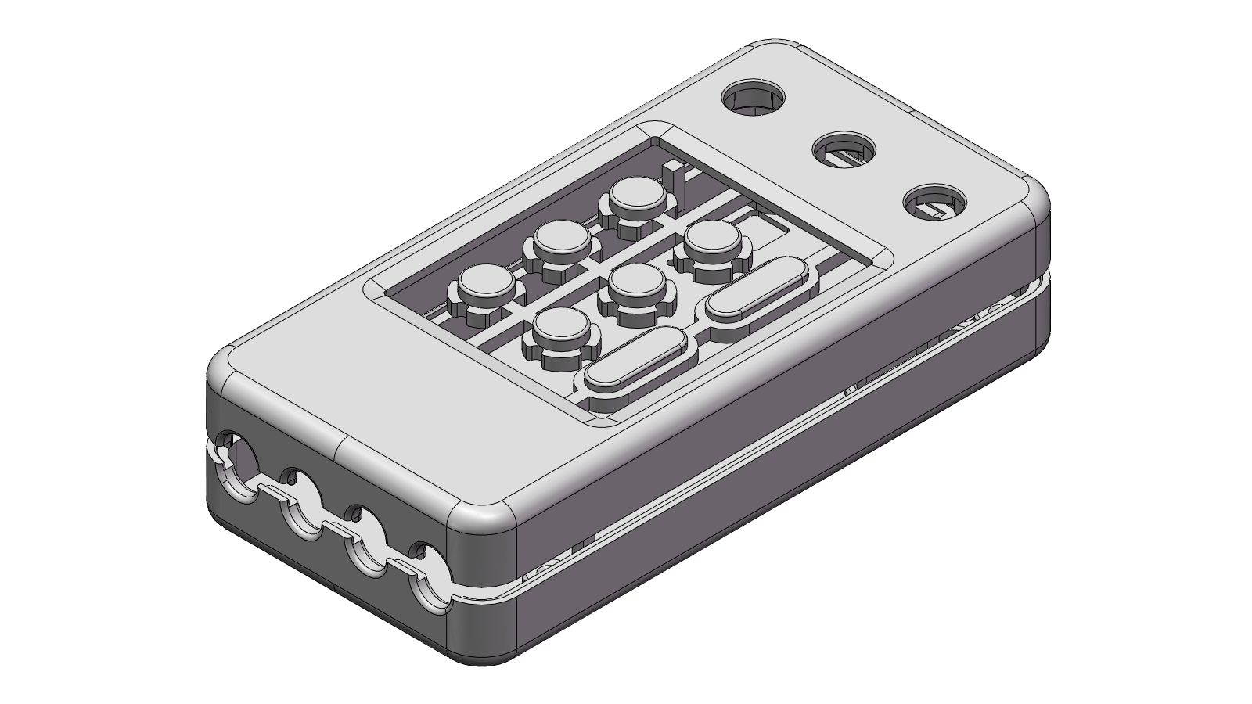
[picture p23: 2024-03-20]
STL/20240320-1521_mR-71_RE6_shell_link_parts.png

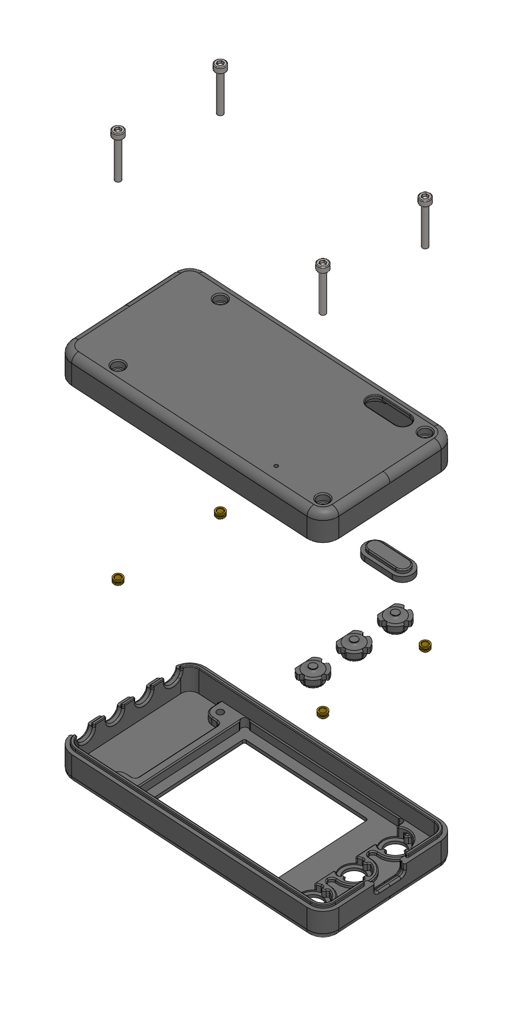
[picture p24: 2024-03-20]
STL/20240320-1521_mR-71_RE6_shell_single_parts.png

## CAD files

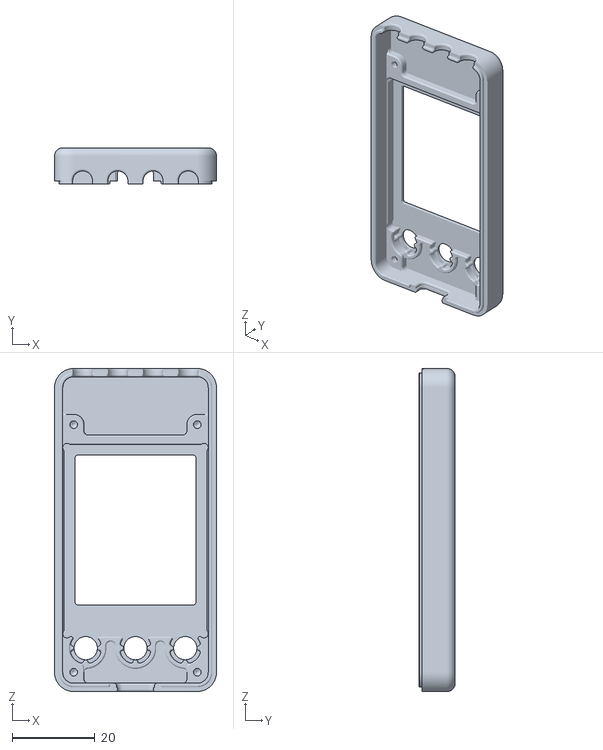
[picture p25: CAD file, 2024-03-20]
STL/single_parts/20240320-1521_mR-71_RE6_shell_top.STL
39.1 x 8.80 x 77.9

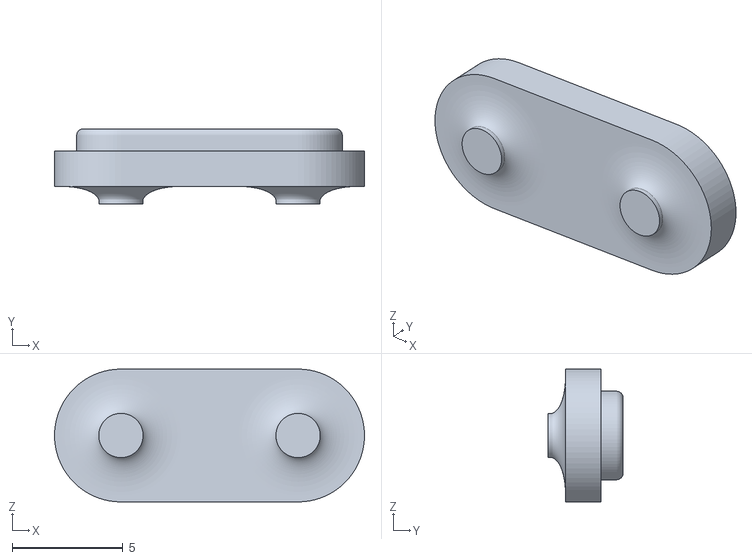
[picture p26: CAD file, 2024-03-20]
STL/single_parts/20240320-1521_mR-71_RE6_button_bottom.STL
14.0 x 3.40 x 6.00

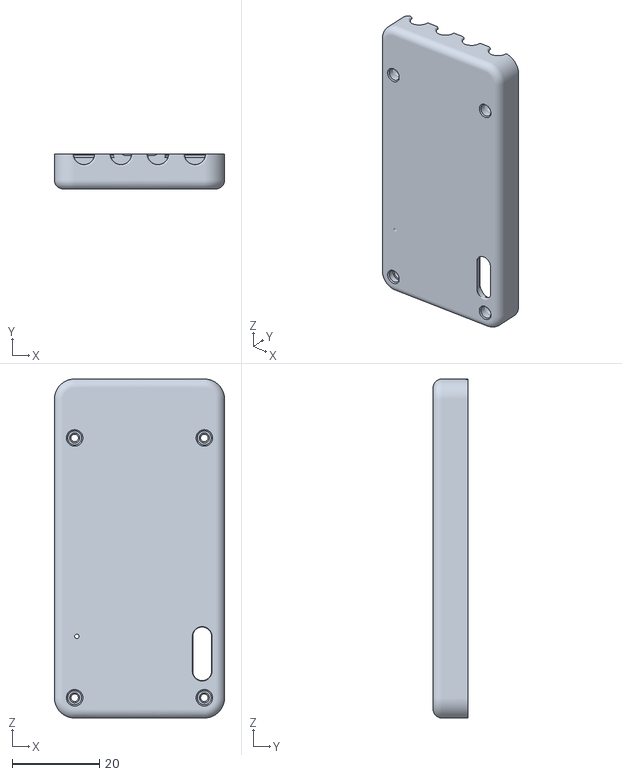
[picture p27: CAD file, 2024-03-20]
STL/single_parts/20240320-1521_mR-71_RE6_shell_bottom.STL
39.1 x 8.00 x 77.9

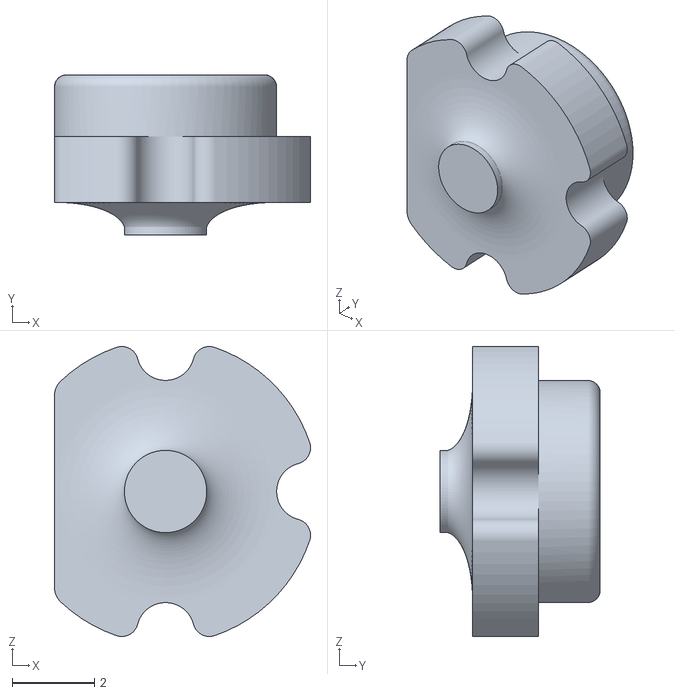
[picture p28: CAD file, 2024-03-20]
STL/single_parts/20240320-1521_mR-71_RE6_button_top.STL
6.22 x 3.90 x 7.05

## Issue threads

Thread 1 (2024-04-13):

关于电阻测试版

megaduo, 2024-04-13:
您好，能否增加一个分板版的电阻测试板gerber，从中间白线出一分为二，方便打板，谢谢

oldgerman, 2024-04-16:
> 您好，能否增加一个分板版的电阻测试板gerber，从中间白线出一分为二，方便打板，谢谢

你好，改好的Gerber已上传：[PCB预览](https://github.com/oldgerman/mR-71-RE/blob/master/Gerber/Kelvin_RES/README.md)
PS：因为PCB板厂一般要求PCB最窄处大于等于5mm，所以从白线分开后，加宽到5mm了

megaduo, 2024-04-17:
感谢！

Closed 2024-04-17.

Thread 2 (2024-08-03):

MR-71-RE

Igor2438, 2024-08-03:
Здравствуйте. Понравился ваш вариант конструкции, но есть вопросы по комплектации. У меня есть доступ только к Алиэкспресс. Вопрос по нахождению дисплея, и разъемов, межплатных и дисплейного. По вашему BOM найти не получается.

oldgerman, 2024-08-21:
Hello, I tried searching for the materials you mentioned on AliExpress, and the following seem to match:

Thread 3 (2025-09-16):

White background on the screen

Fill-in0, 2025-09-16:
Hi 😊
I have already repeated several of your projects and I have a few questions about that project.

1. When I flashed yours modified firmware I got white background on the screen.

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

When I flashed original firmware I got correct black background, but as we know that firmware not compatible with this type of display and on the edges of screen we can see some artifacts.

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

What am I doing wrong? I used STM Cube according to you guide.

2. What components you soldered on this side of test board? Can you send a photo of both side?

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

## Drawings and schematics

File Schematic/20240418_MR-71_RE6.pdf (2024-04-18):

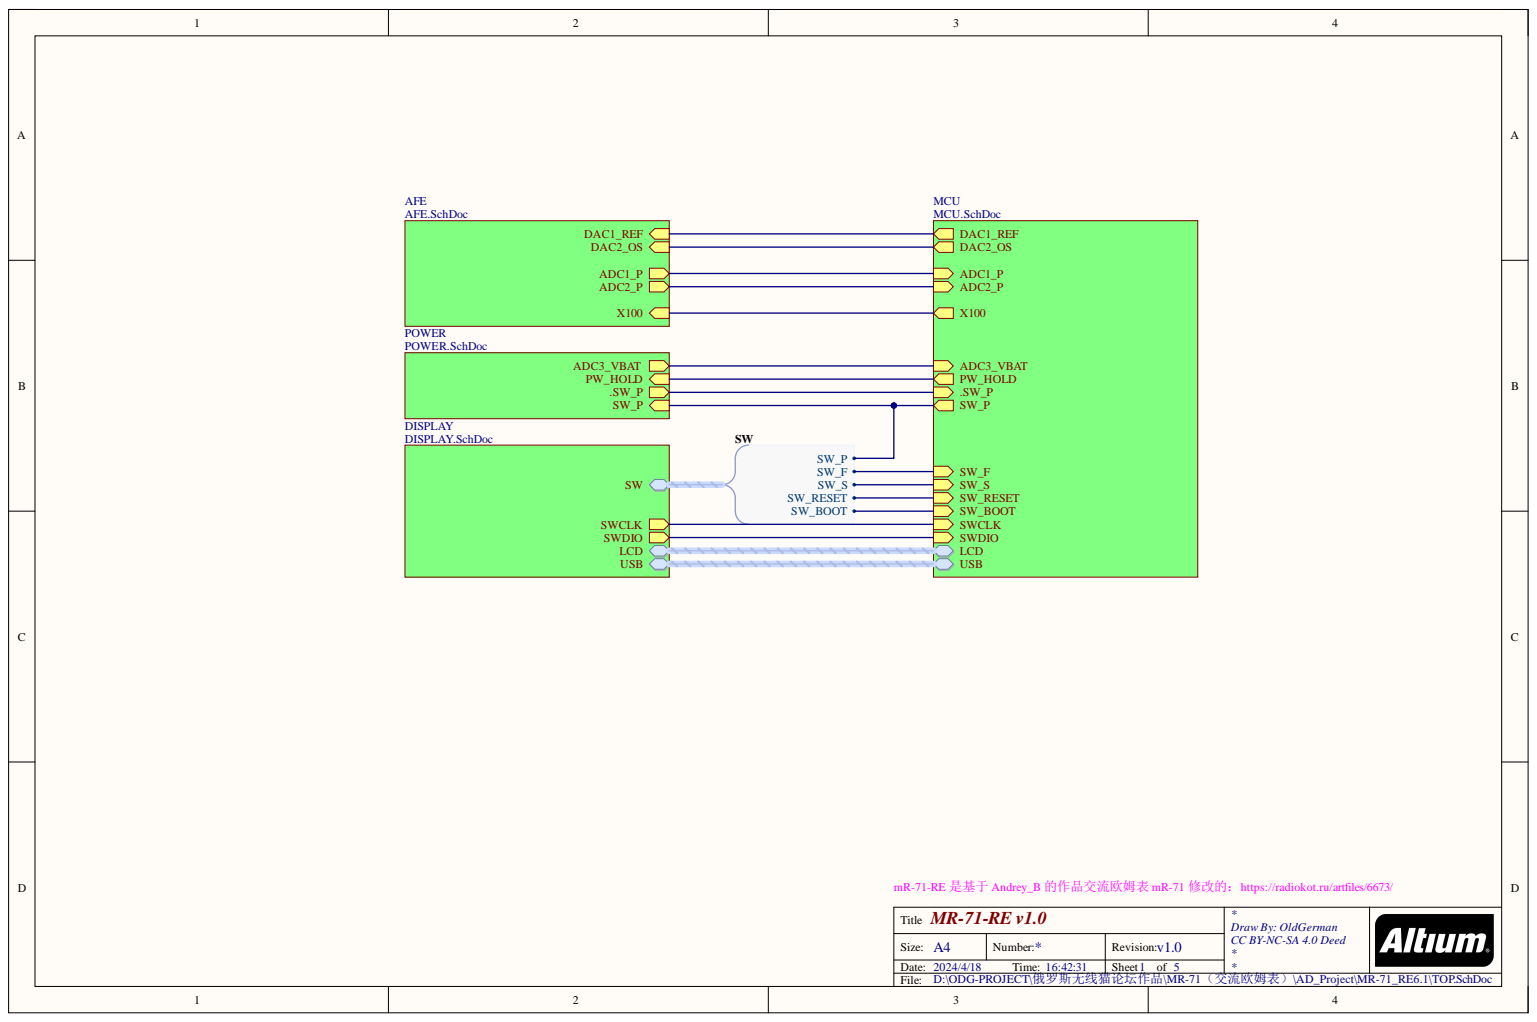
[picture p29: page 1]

mR-71-RE 是基于 Andrey_B 的作品交流欧姆表 mR-71 修改的：https://radiokot.ru/artfiles/6673/

Draw By: OldGerman
CC BY-NC-SA 4.0 Deed

D:\ODG-PROJECT\俄罗斯无线猫论坛作品\MR-71（交流欧姆表）\AD_Project\MR-71_RE6.1\TOP.SchDoc
File:

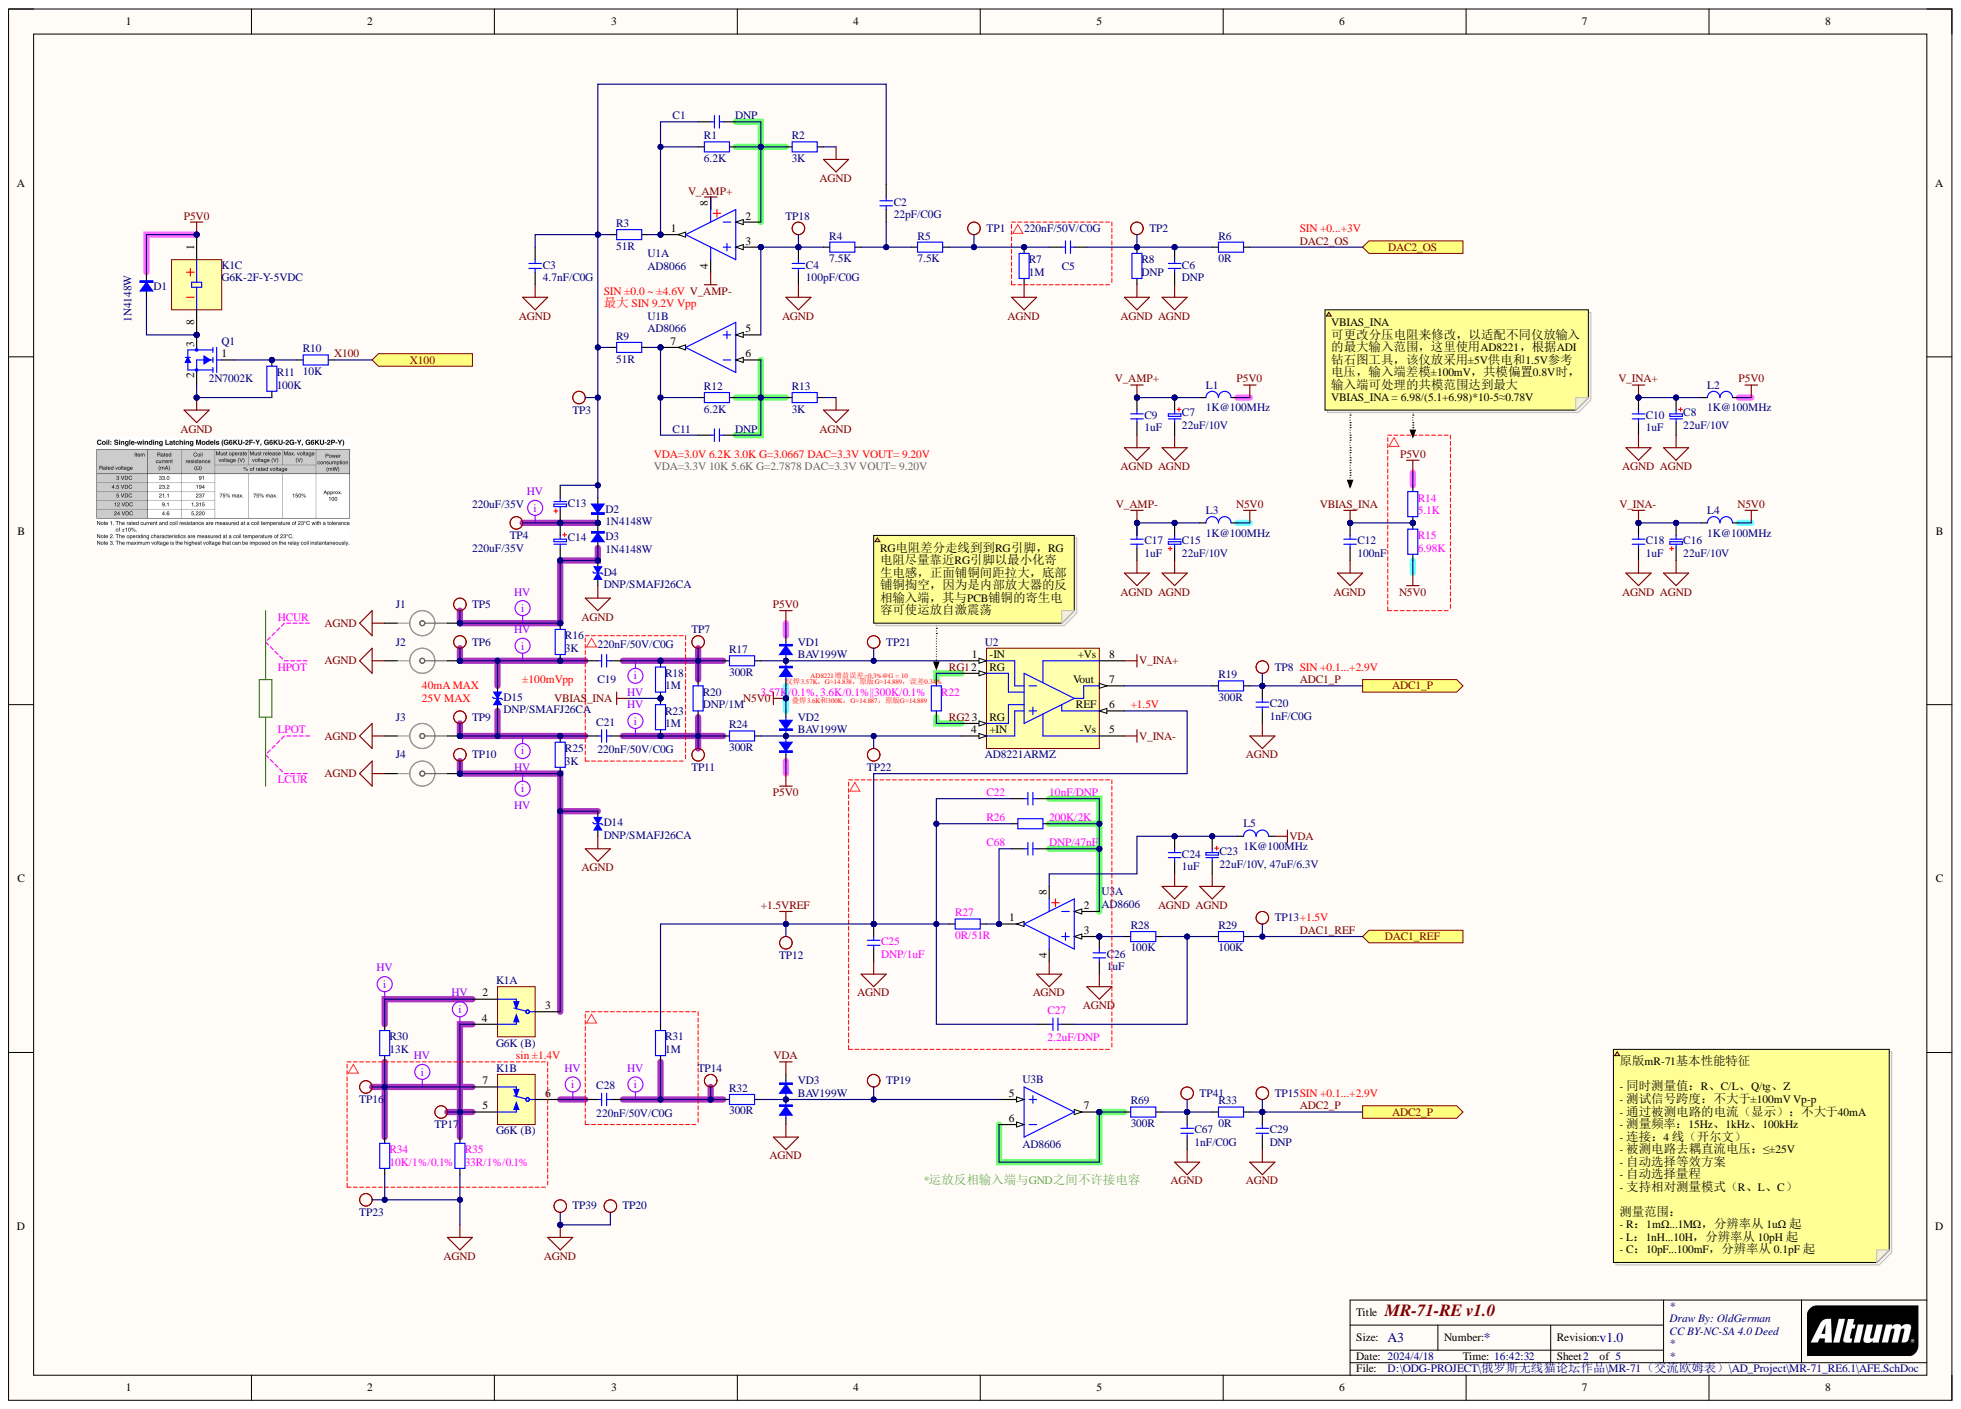
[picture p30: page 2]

TP12 | | | C25 DNP/1uF | 3

Draw By: OldGerman
CC BY-NC-SA 4.0 Deed

D:\ODG-PROJECT\俄罗斯无线猫论坛作品\MR-71（交流欧姆表）\AD_Project\MR-71_RE6.1\AFE.SchDoc

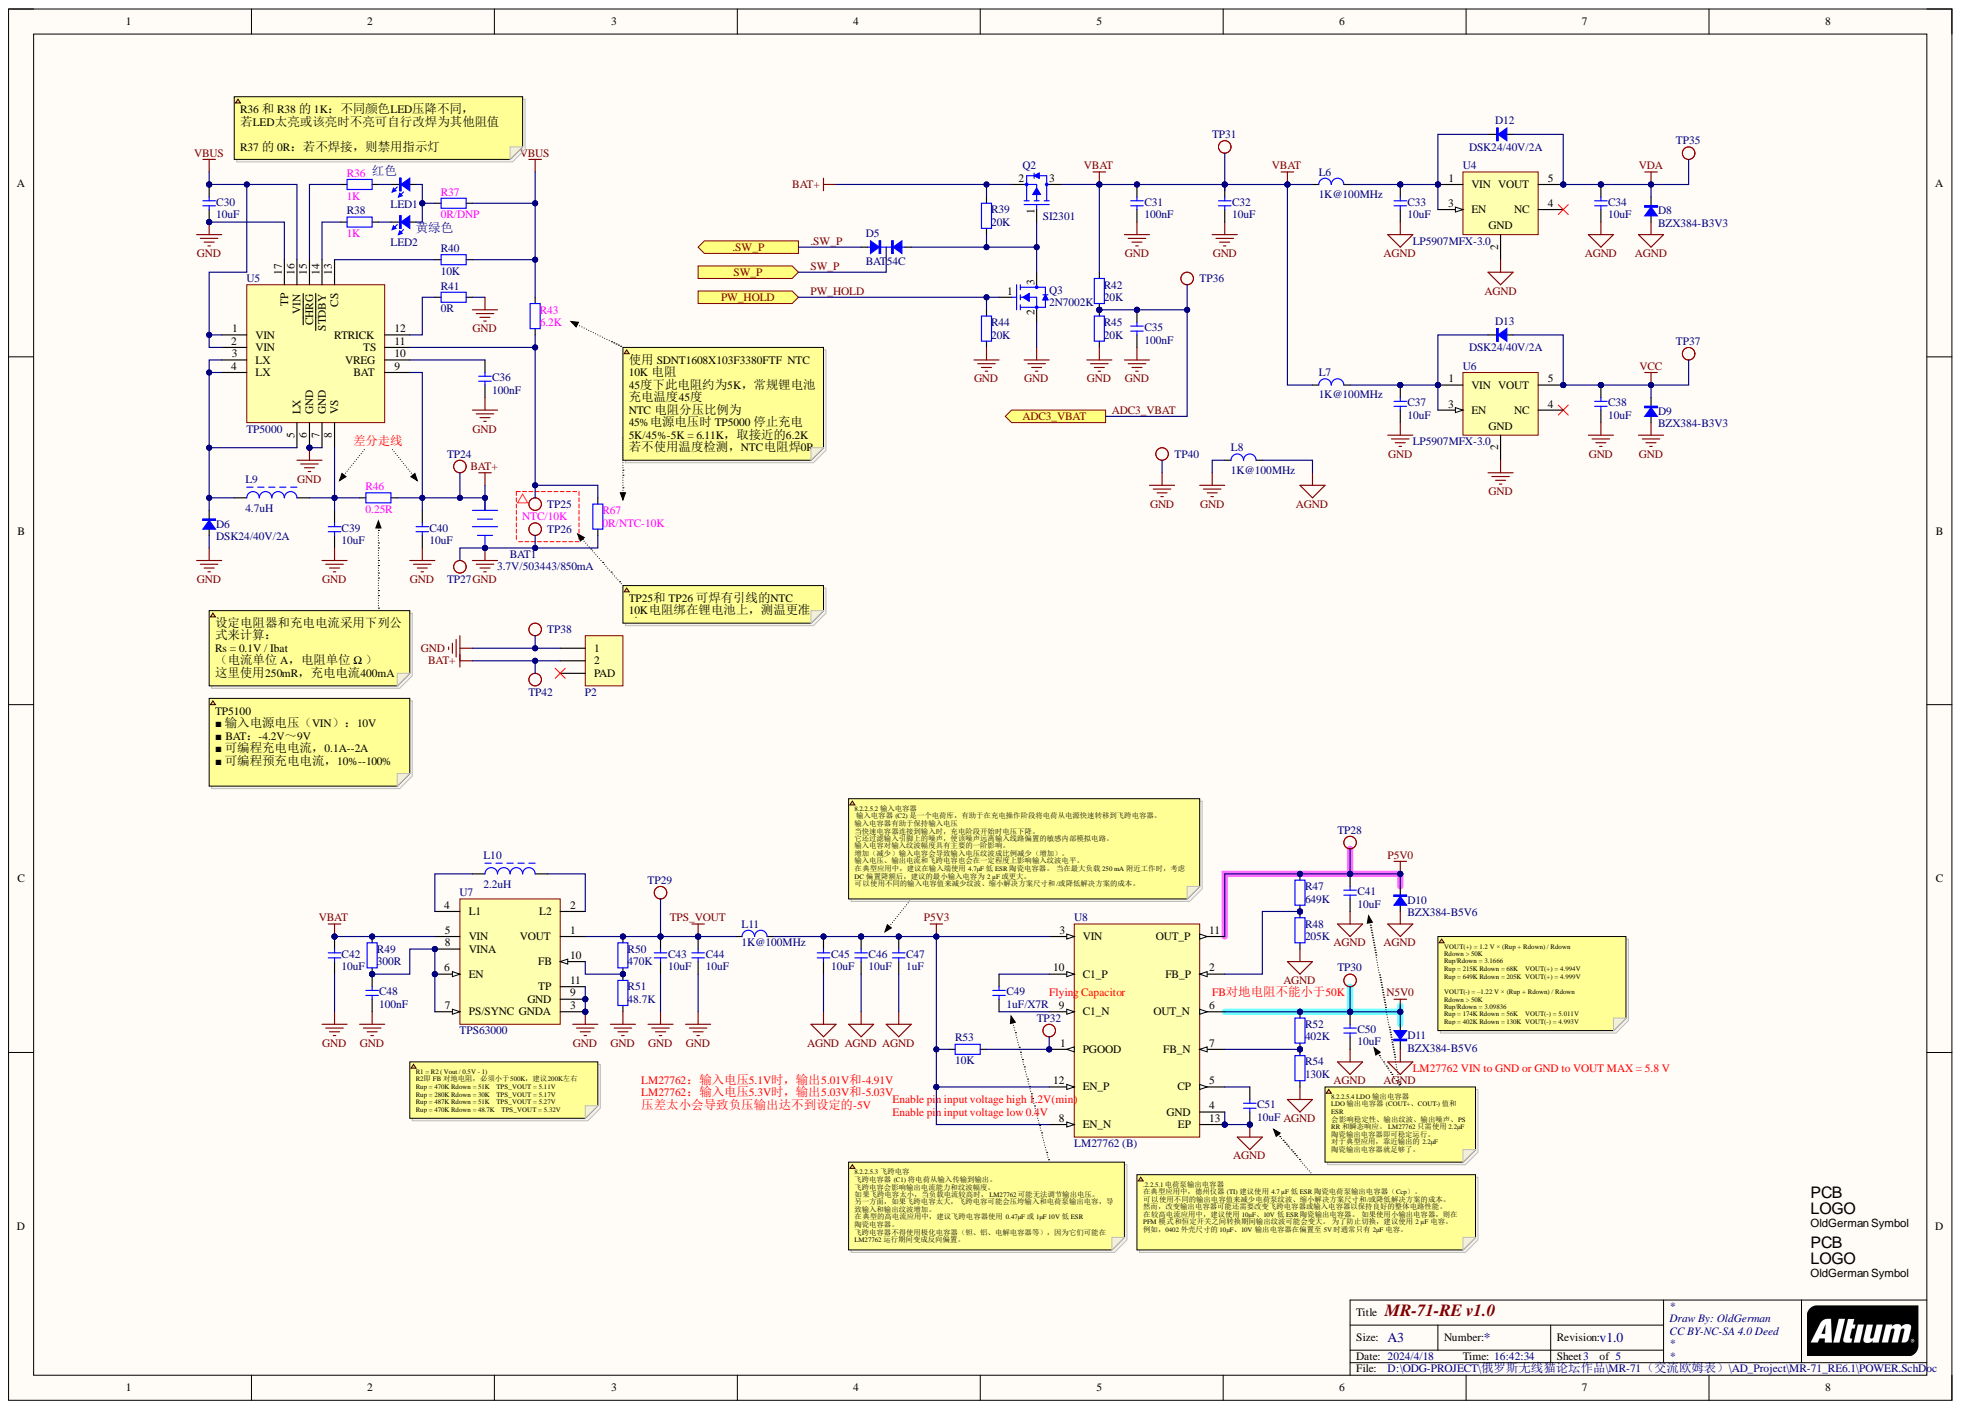
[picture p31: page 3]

8.2.2.5.2 输入电容器
输入电容器 (C2) 是一个电荷库，有助于在充电操作阶段将电荷从电源快速转移到飞跨电容器。 输入电容器有助于保持输入电压

当快速电容器连接到输入时，充电阶段开始时电压下降。
它还过滤输入引脚上的噪声，使该噪声远离输入线路偏置的敏感内部模拟电路。
输入电容对输入纹波幅度具有主要的一阶影响。
增加（减少）输入电容会导致输入电压纹波成比例减少（增加）。
输入电压、输出电流和飞跨电容也会在一定程度上影响输入纹波电平。
在典型应用中，建议在输入端使用 4.7μF 低 ESR 陶瓷电容器。 当在最大负载 250 mA 附近工作时，考虑
DC 偏置降额后，建议的最小输入电容为 2 µF 或更大。 可以使用不同的输入电容值来减少纹波、缩小解决方案尺寸和/或降低解决方案的成本。

VOUT(+) = 1.2 V × (Rup + Rdown) / Rdown
Rdown > 50K
Rup/Rdown = 3.1666
Rup = 215K Rdown = 68K VOUT(+) = 4.994V
Rup = 649K Rdown = 205K VOUT(+) = 4.999V

VOUT(-) = –1.22 V × (Rup + Rdown) / Rdown
Rup/Rdown = 3.09836
Rup = 174K Rdown = 56K VOUT(-) = 5.011V
Rup = 402K Rdown = 130K VOUT(-) = 4.993V

BZX384-B5V6
LM27762 VIN to GND or GND to VOUT MAX = 5.8 V
AGND

Enable pin input voltage high 1.2V(min)
Enable pin input voltage low 0.4V

8.2.2.5.4 LDO 输出电容器
LDO 输出电容器 (COUT+、COUT-) 值和
ESR
会影响稳定性、输出纹波、输出噪声、PS
RR 和瞬态响应。 LM27762 只需使用 2.2μF
陶瓷输出电容器即可稳定运行。
对于典型应用，靠近输出的 2.2μF
陶瓷输出电容器就足够了。

.2.2.5.1 电荷泵输出电容器 在典型应用中，德州仪器 (TI) 建议使用 4.7 µF 低 ESR 陶瓷电荷泵输出电容器（Ccp）。

可以使用不同的输出电容值来减少电荷泵纹波、缩小解决方案尺寸和/或降低解决方案的成本。
然而，改变输出电容器可能还需要改变飞跨电容器或输入电容器以保持良好的整体电路性能。
在较高电流应用中，建议使用 10μF、10V 低 ESR 陶瓷输出电容器。 如果使用小输出电容器，则在
PFM 模式和恒定开关之间转换期间输出纹波可能会变大。 为了防止切换，建议使用 2 µF 电容。 例如，0402 外壳尺寸的 10μF、10V 输出电容器在偏置至 5V 时通常只有 2μF 电容。

Draw By: OldGerman
CC BY-NC-SA 4.0 Deed

D:\ODG-PROJECT\俄罗斯无线猫论坛作品\MR-71（交流欧姆表）\AD_Project\MR-71_RE6.1\POWER.SchDoc

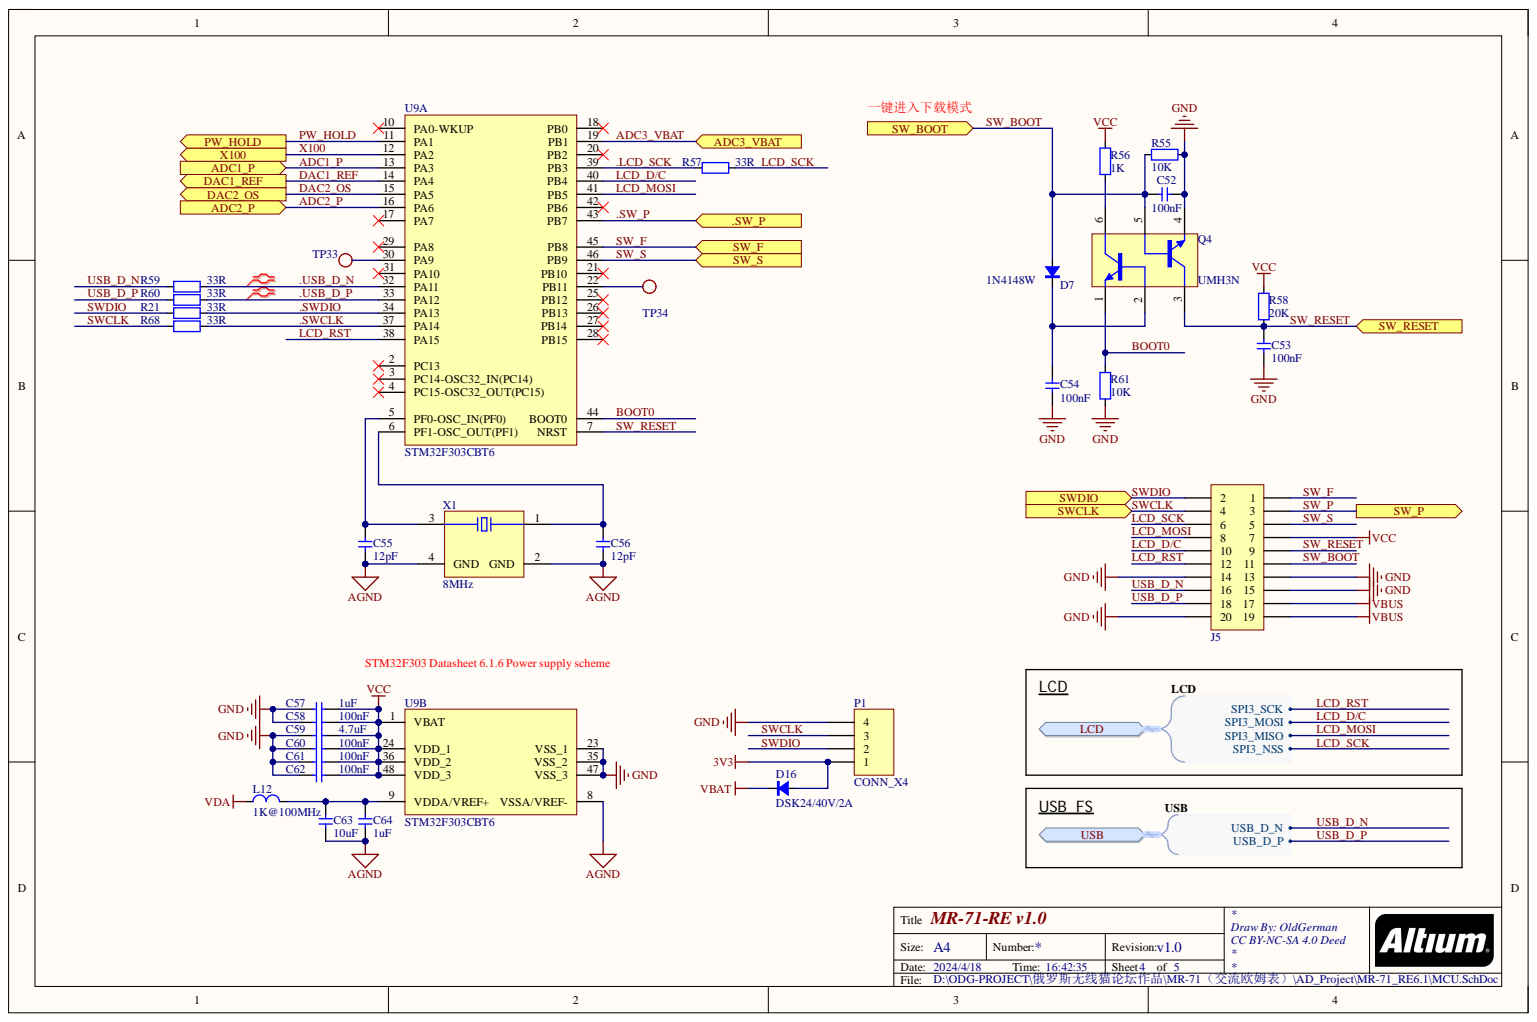
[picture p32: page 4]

STM32F303 Datasheet 6.1.6 Power supply scheme

Draw By: OldGerman
CC BY-NC-SA 4.0 Deed

D:\ODG-PROJECT\俄罗斯无线猫论坛作品\MR-71（交流欧姆表）\AD_Project\MR-71_RE6.1\MCU.SchDoc

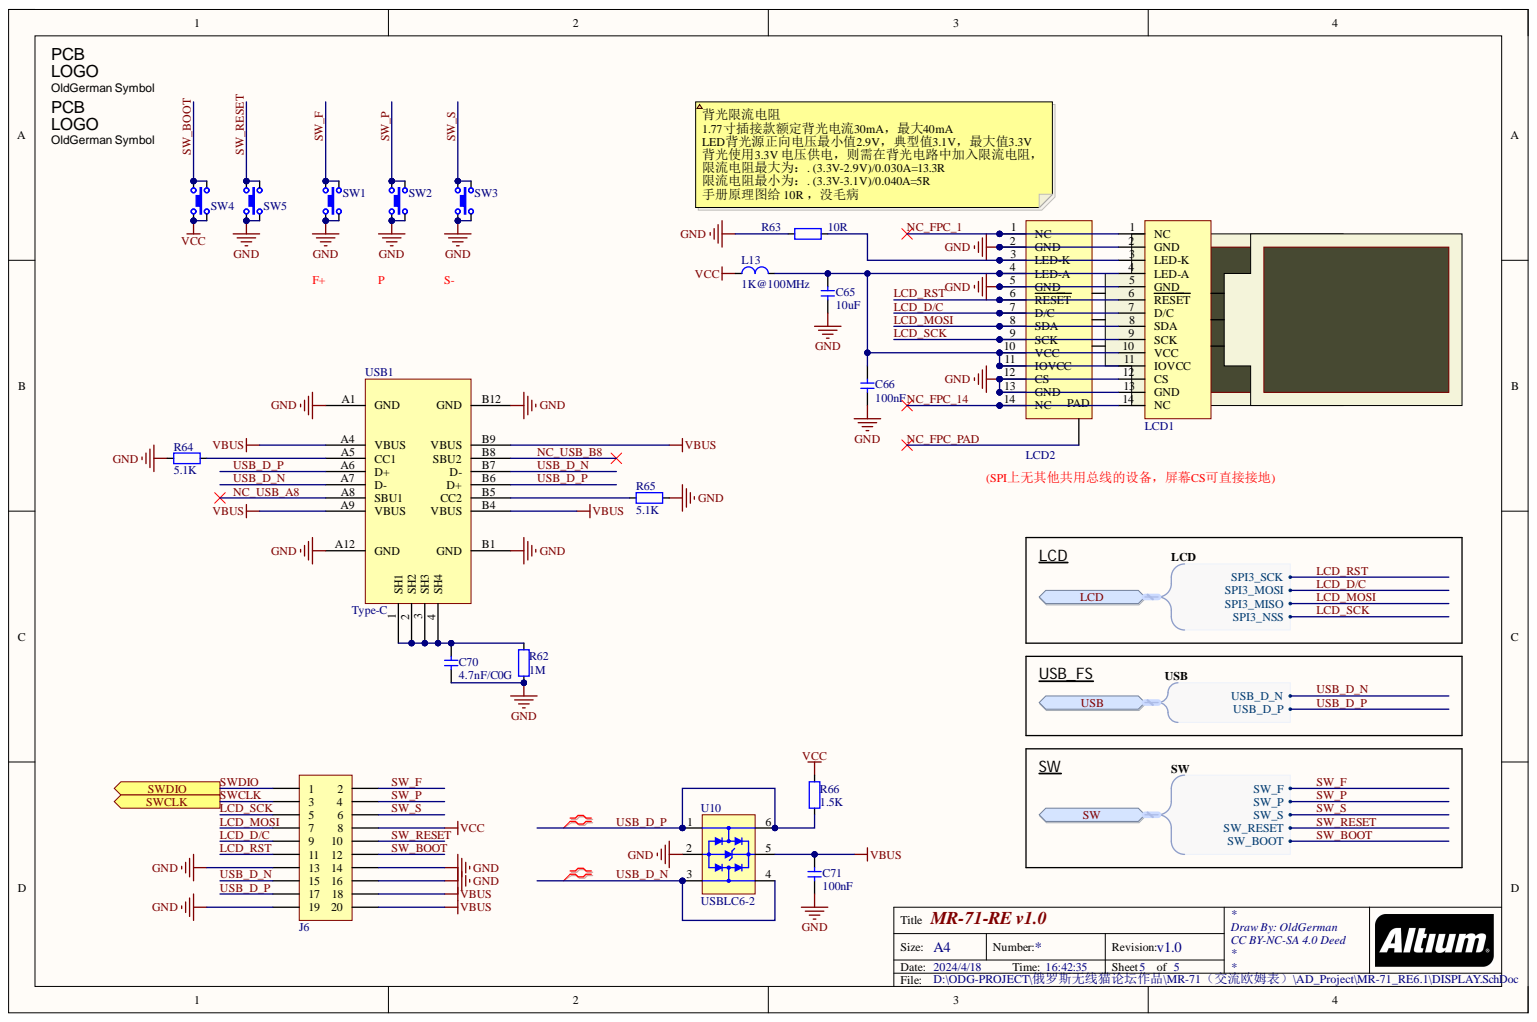
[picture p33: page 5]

GND 2 | GND 2
LED-K 3 | | LED-K 3
LED-A 4

RESET 6 | | RESET 6

VCC 10 | | VCC 10

NC 14 PAD

Draw By: OldGerman
CC BY-NC-SA 4.0 Deed

D:\ODG-PROJECT\俄罗斯无线猫论坛作品\MR-71（交流欧姆表）\AD_Project\MR-71_RE6.1\DISPLAY.SchDoc

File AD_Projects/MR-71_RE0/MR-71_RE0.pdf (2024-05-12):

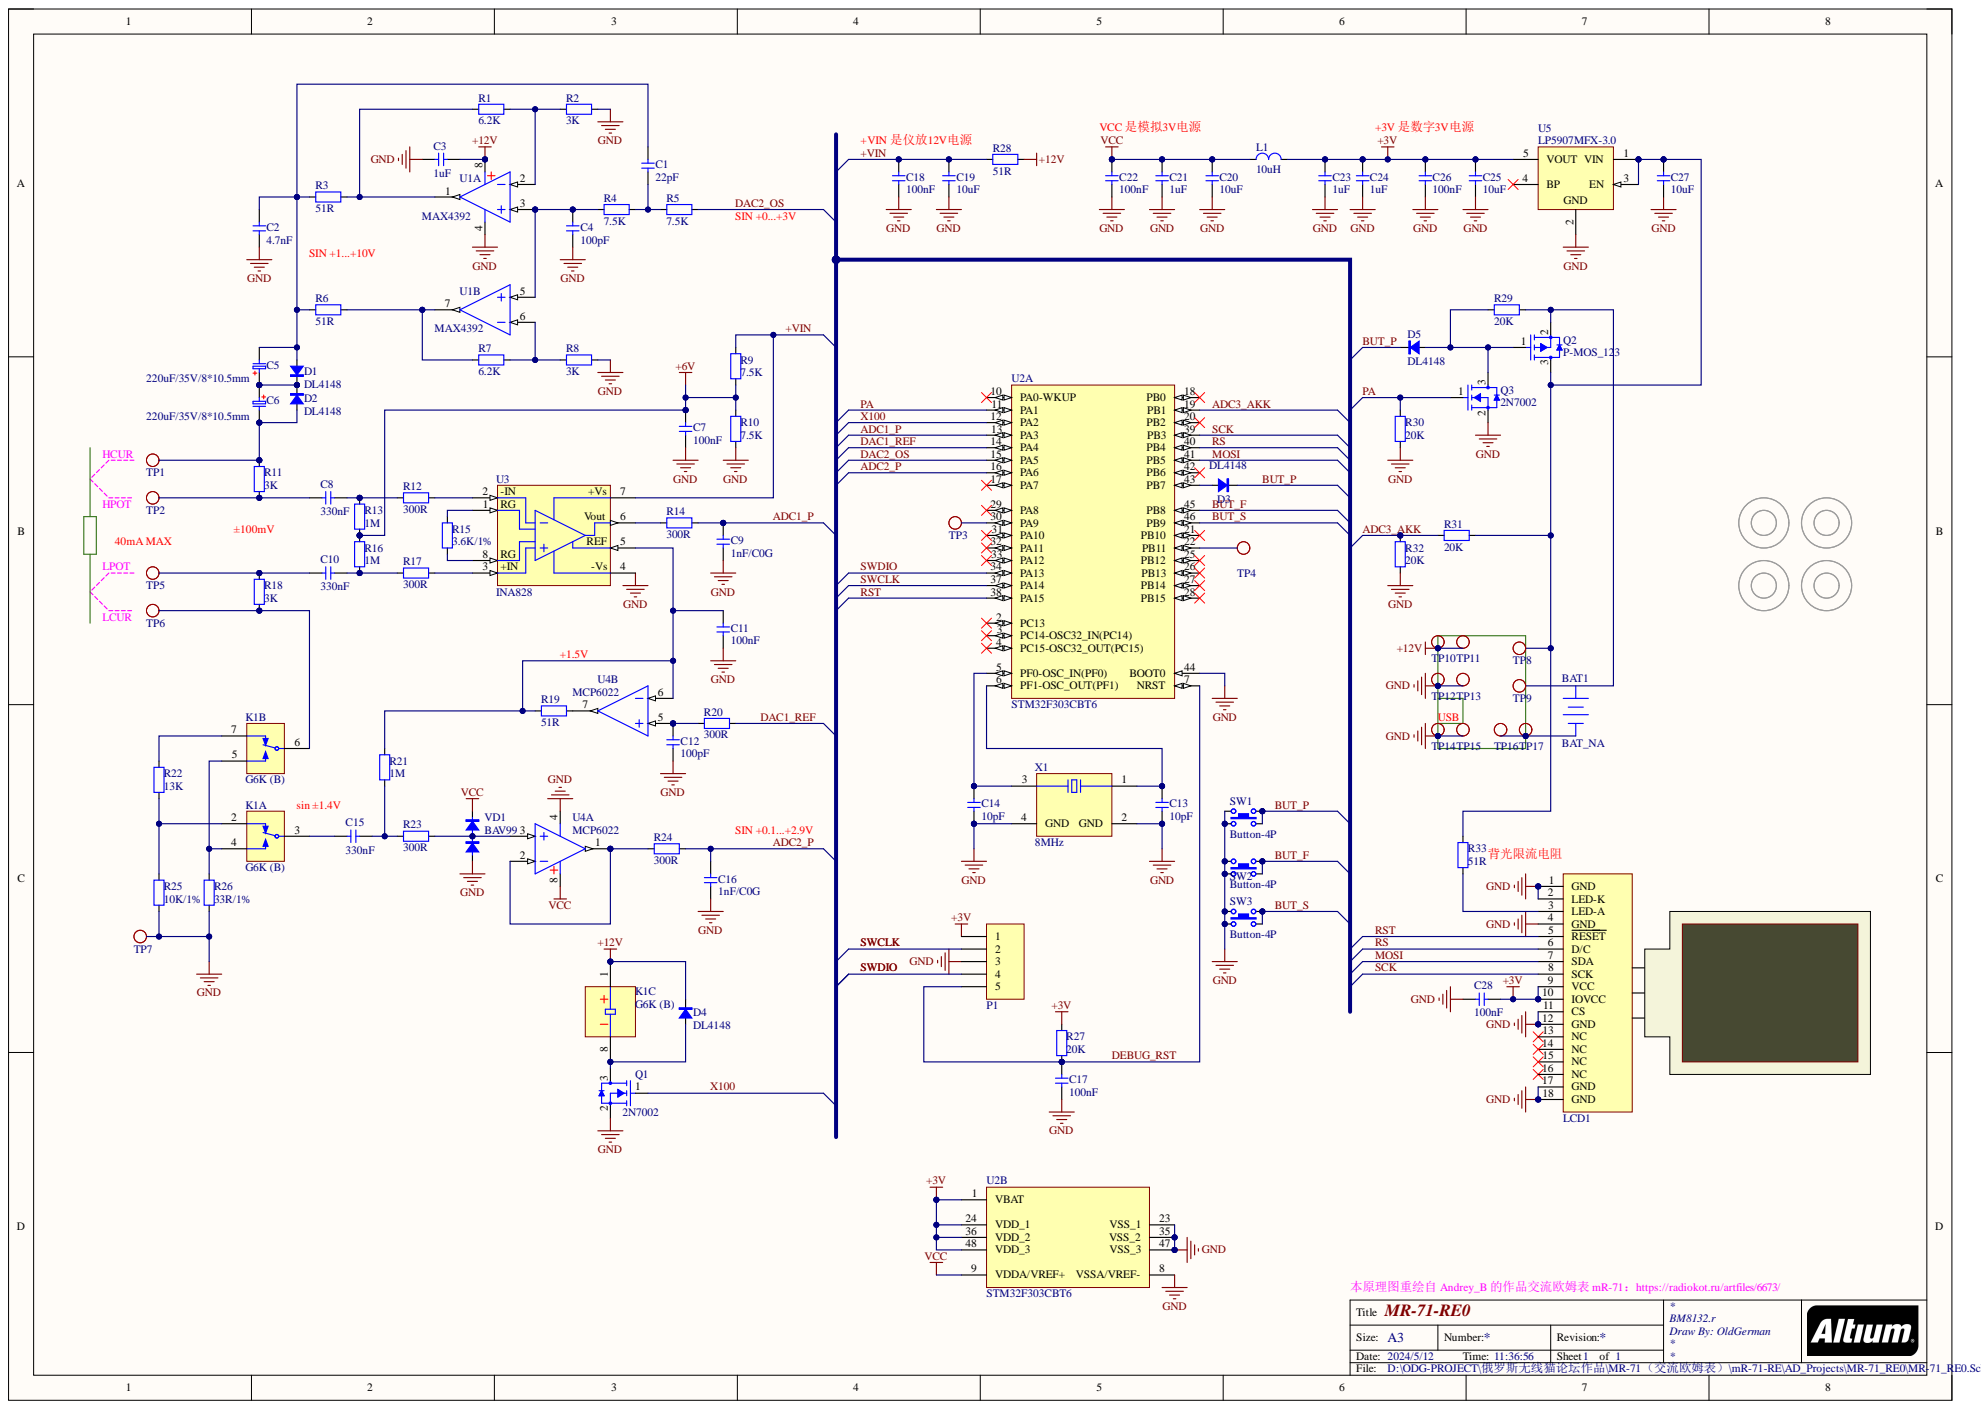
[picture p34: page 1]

PF1-OSC_OUT(PF1) 6

本原理图重绘自 Andrey_B 的作品交流欧姆表 mR-71：https://radiokot.ru/artfiles/6673/
Title

D:\ODG-PROJECT\俄罗斯无线猫论坛作品\MR-71（交流欧姆表）\mR-71-RE\AD_Projects\MR-71_RE0\MR-71_RE0.SchDoc
File:

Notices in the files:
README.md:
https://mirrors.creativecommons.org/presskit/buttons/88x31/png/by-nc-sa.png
